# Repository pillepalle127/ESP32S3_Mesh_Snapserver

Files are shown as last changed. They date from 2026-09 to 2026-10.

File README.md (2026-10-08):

<picture>
  <source media="(prefers-color-scheme: dark)" srcset="docs/logo/snapmesh-logo-dark.svg">
  SnapMesh
</picture>

# ESP32-S3 Mesh Snapserver

**Stand:** 2026-09-29 · **English:** [README.en.md](README.en.md)

Mehrere Lautsprecher spielen synchron dieselbe Musik, ohne Router, PC oder Kabel dazwischen. Die ESP32-S3 bauen sich
ihr eigenes Funknetz (ESP-Mesh-Lite) und reichen das Signal von Gerät zu Gerät weiter.

Damit könnt ihr:

* eine Quelle einspeisen und überall hören,
* Lautstärke und Verzögerung für jeden Lautsprecher einzeln einstellen,
* Durchsagen vom Handy machen,
* einen Subwoofer über die eingebaute Weiche anschließen,
* vorhandene Snapcast-Clients (PC, Android, iOS) und Snapcast-Apps mitnutzen.

Im Kern stecken zwei Funktionen, die sich eigentlich widersprechen: **Musik** soll ohne Aussetzer laufen und bekommt
dafür einige Sekunden Puffer. **Durchsagen** sollen sofort zu hören sein (keine Latenz). Ich habe es
auf ~90 ms runtergeschafft.

Alle Geräte haben dieselbe Firmware. Eins ist der **Server**, alle anderen sind **Clients**.

---

## Installation

Firmware und App liegen fertig unter [Releases](https://github.com/pillepalle127/ESP32S3_Mesh_Snapserver/releases).
Geflasht wird aus dem Browser, eine Entwicklungsumgebung ist nicht nötig.

**Benötigt:** ein ESP32-S3-Board je Standort mit mindestens 4 MB Flash und **Octal-PSRAM** (z. B. N16R8, N8R8), ein
USB-Kabel mit Datenleitungen und Chrome oder Edge am PC. Für die App ein Android-Handy.

### 1. Firmware aufspielen

1. **[Flash-Seite](https://pillepalle127.github.io/ESP32S3_Mesh_Snapserver/)** öffnen, Board anschließen (bei zwei
   Buchsen die mit „USB“).
2. **Installieren**, „USB JTAG/serial debug unit“ wählen, **Verbinden**.
3. **Bei Updates „Erase device“ nicht anhaken**, sonst sind die Einstellungen weg.

Taucht das Board nicht auf: anderes Kabel, oder BOOT halten und kurz RST drücken. Ohne Chrome geht es mit
[esptool](https://github.com/espressif/esptool/releases) und den Einzeldateien aus dem Release:
```bash
esptool --chip esp32s3 --before usb_reset write_flash 0x0 bootloader.bin 0x8000 partition-table.bin 0x10000 snapmesh-app.bin 0x3d0000 ota_data_initial.bin
```

### 2. Einrichten

1. Mit dem offenen WLAN **`ESP32_provisioning_…`** verbinden und **http://192.168.5.1/** öffnen.
2. Rolle, Mesh-Name und Passwort eintragen (auf allen Geräten gleich), **Save**.

Erst den Server einrichten, dann die Clients. Mehr unter [Web-UI](#web-ui).

### 3. App (Android)

**`SnapAnnounce-….apk`** vom [Release](https://github.com/pillepalle127/ESP32S3_Mesh_Snapserver/releases) aufs Handy
laden und installieren. Handy ins Mesh-WLAN, App öffnen, fertig.

---

## Hardware

Zwei Aufbauten laufen bei mir:

* **Komplettsystem** im Verstärker: PCM5102A als Ausgang, TinySine AudioB I2S V2r0 als Bluetooth-Eingang, der über
  einen Pegelwandler TXB0104 am ESP hängt.
* **[SnapStreamer](#bauvorschlag-snapstreamer):** ein Bauvorschlag für einen reinen Empfänger mit PCM5102A.

Geeignet ist jeder ESP32-S3 mit mindestens 4 MB Flash, Octal-PSRAM und USB-Serial/JTAG, zum Beispiel ein
YD-ESP32-S3 N16R8
([Schaltplan V1.4](https://github.com/vcc-gnd/YD-ESP32-S3/blob/main/5-public-YD-ESP32-S3-Hardware%20info/YD-ESP32-S3-SCH-V1.4.pdf)).
Zwei 10-kΩ-Potis sind optional. Als Status-LED dient die WS2812, die auf vielen Boards schon sitzt. Die
Standardbelegung könnt ihr ändern (siehe [Pins](#pins)):

| GPIO | Funktion |
|---|---|
| 12 | BCLK (PCM5102A BCK, TinySine BCLK) |
| 14 | LRCLK (PCM5102A LCK, TinySine LRCLK) |
| 11 | DIN ← TinySine DOUT |
| 13 | DOUT → PCM5102A DIN |
| 10 | Lautstärke-Poti (Schleifer) |
| – | Delay-Poti (Vorgabe: keiner) |
| – | Ein/Aus-Taster gegen GND (Vorgabe: keiner) |
| 48 | WS2812-Status-LED |

---

## Bauvorschlag: SnapStreamer

Ihr habt einen Verstärker oder Aktivlautsprecher und wollt ihn ins Mesh holen? Der SnapStreamer ist meine Idee
dazu: ESP32-S3, DAC und Akku so dicht wie möglich in einem kleinen Gehäuse. Schrumpfschlauch oder ein vorhandenes
Gehäuse tun es natürlich auch.

<table>
  <tr>
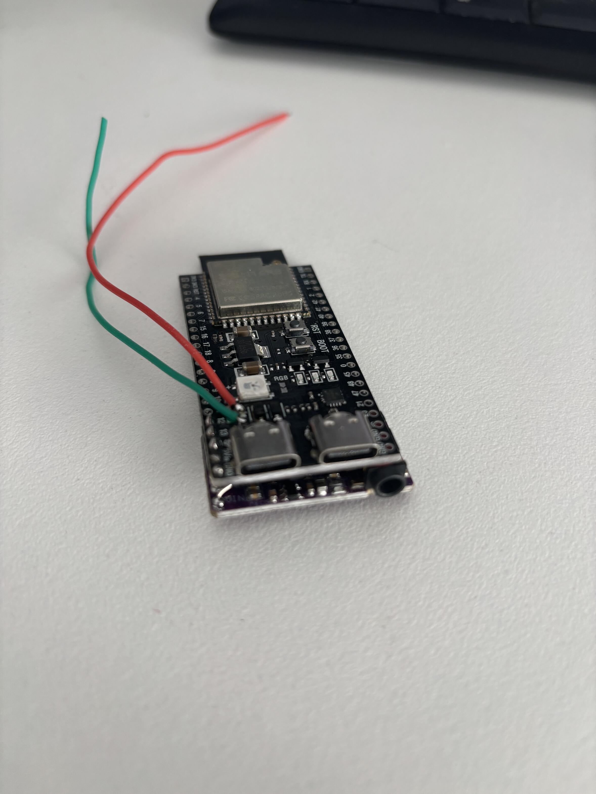
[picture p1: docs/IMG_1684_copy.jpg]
Platine von oben: ESP32-S3-Board mit dem PCM5102A darunter
    <td valign="top"></td>
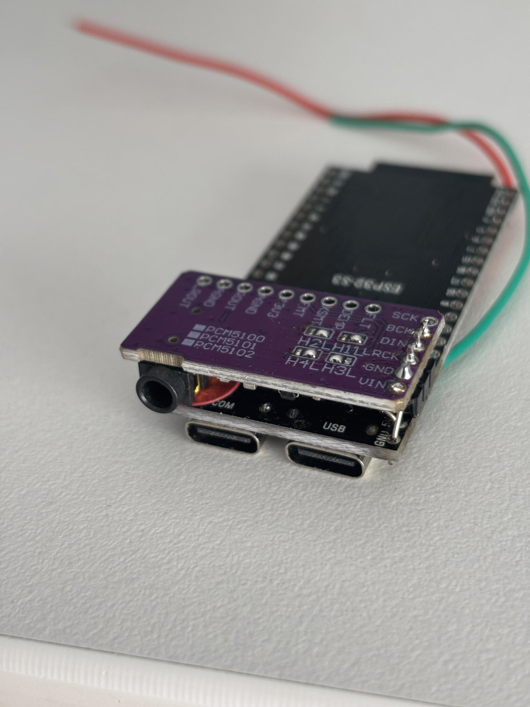
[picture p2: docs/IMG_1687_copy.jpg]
Von unten: PCM5102A-Modul unter dem ESP32-S3-Board
    <td valign="top"></td>
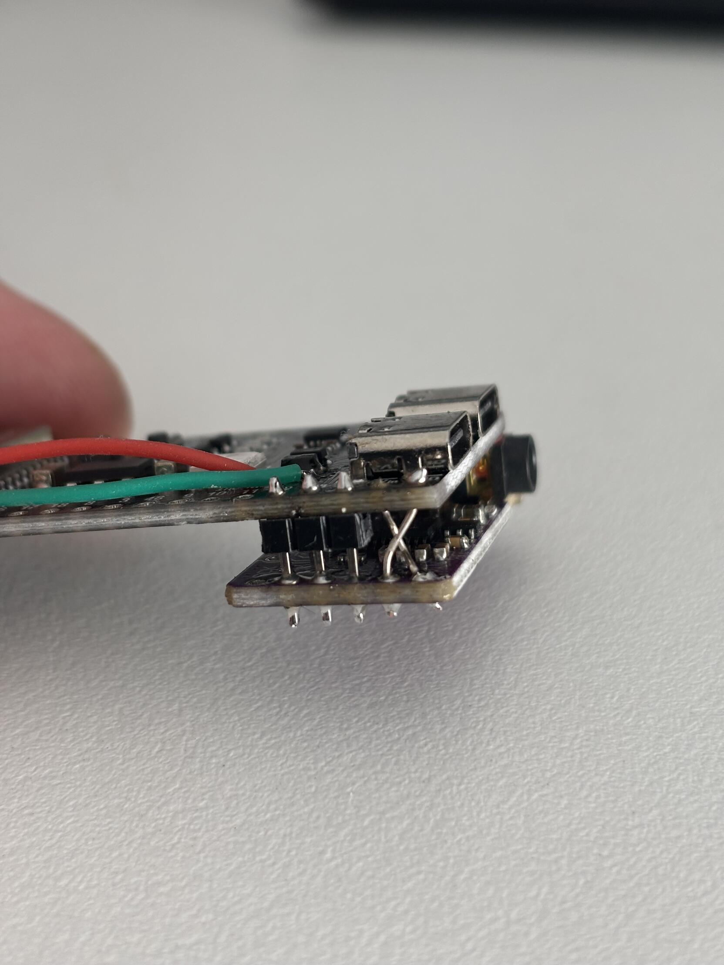
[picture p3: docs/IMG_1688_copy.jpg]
Von der Seite: GND und VIN gekreuzt
    <td valign="top"></td>
  </tr>
</table>

Der PCM5102A sitzt über kurze Stiftleisten direkt unter dem ESP32-S3-Board. Die LEDs bleiben sichtbar, RST und
BOOT erreichbar, Klinke und USB-Buchsen liegen auf einer Ebene an einer Stirnseite. GND und VIN müssen dabei
gekreuzt werden (in der Seitenansicht als X zu sehen).

Die rote und grüne Leitung (optional) führen die 5 V der ESP-Buchse zum TP4056: eine Buchse zum Programmieren und
Laden. Ladestrom auf 500 mA gesenkt (Verlustleistung). Der Akku hängt an VIN, nicht an 3V3: Die Zelle hat bis 4,2 V,
der ESP verträgt max. 3,6 V. Die Alternative wäre ein Buck-Boost-Wandler. Ein Poti mit Schalter schaltet ein und
regelt die Lautstärke.

> [!WARNING]
> Li-Ionen-Akkus können brennen, wenn sie kurzgeschlossen, beschädigt oder falsch geladen werden. Nehmt nur Zellen
> und Lademodule mit Schutzschaltung, isoliert offene Kontakte, quetscht die Zelle nicht ins Gehäuse und ladet nicht
> unbeaufsichtigt.

### Stückliste

| Teil | Typ / Hinweis | Anzahl |
|---|---|---|
| ESP32-S3-Board | ≥ 4 MB Flash, Octal-PSRAM, z. B. YD-ESP32-S3 N16R8 | 1 |
| WLAN-Antenne | optional, 2,4 GHz mit U.FL-Kabel; nur für Boards mit U.FL-Anschluss, verbessert mit guter Antenne den Empfang | 1 |
| DAC-Modul | PCM5102A mit 3,5-mm-Klinkenbuchse | 1 |
| Lademodul | TP4056 mit Schutzschaltung (DW01) | 1 |
| Akku | 18650 Li-Ion mit Zellkontakten | 1 |
| Poti mit Schalter | 10 kΩ linear (B10K), Schalter für die Versorgung, mit Drehknopf | 1 |
| Gehäuse | 3D-Druck: Unterteil (PETG), Deckel (PETG transparent) | 1 |

### Gehäuse

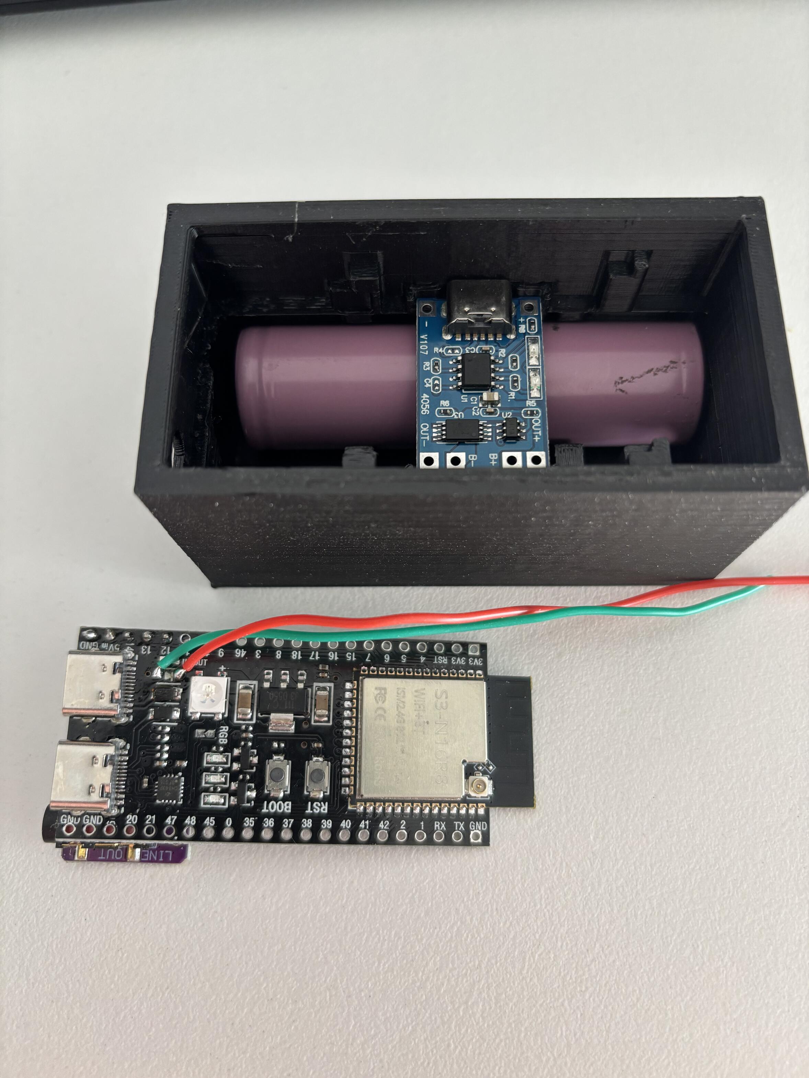
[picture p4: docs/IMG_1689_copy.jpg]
Gehäuseunterteil mit 18650-Zelle und TP4056, daneben die Platine


<table>
  <tr>
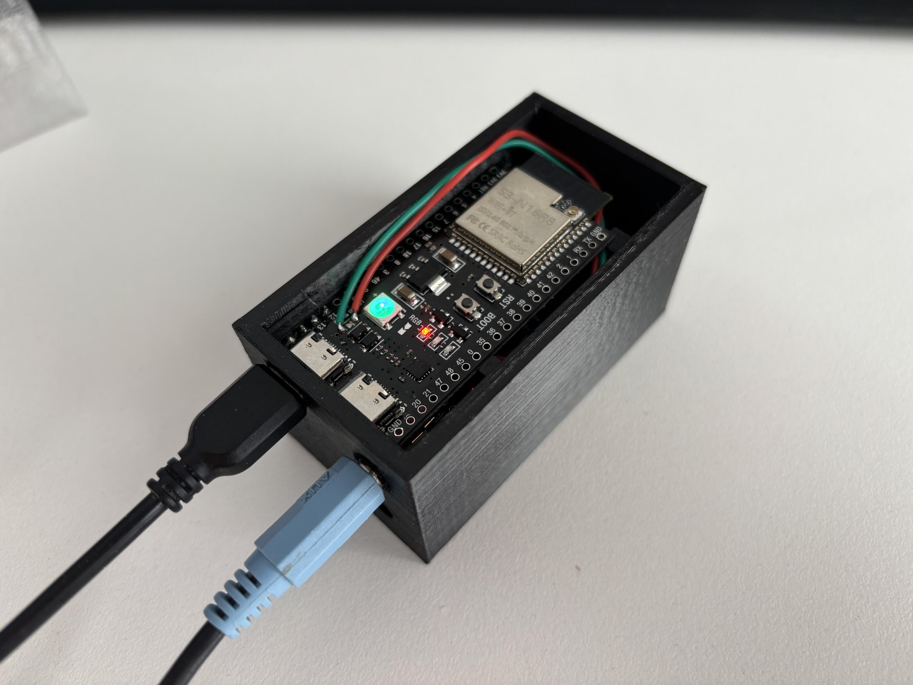
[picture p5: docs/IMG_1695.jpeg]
Offenes Gehäuse mit Platine, USB und Klinke angesteckt
    <td valign="top"></td>
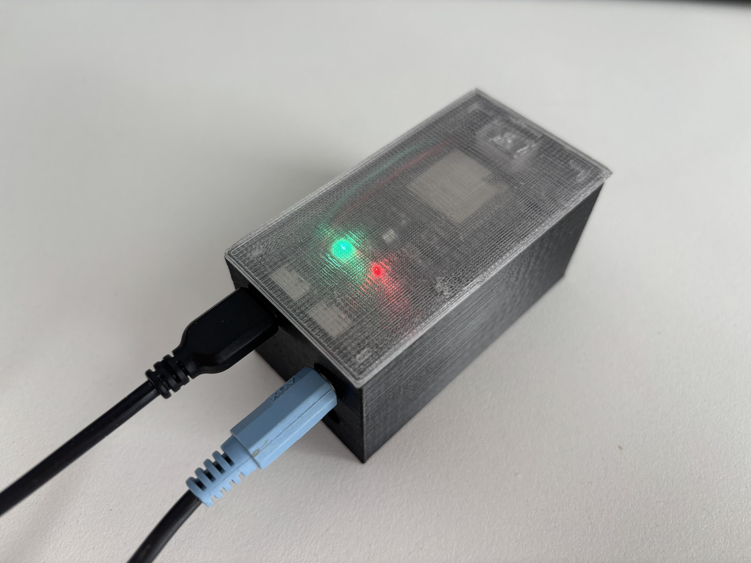
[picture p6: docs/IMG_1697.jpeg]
Geschlossenes Gehäuse, die Status-LED leuchtet durch den Deckel
    <td valign="top"></td>
  </tr>
</table>

Unten im Gehäuse liegen Akku und Lademodul, darüber die Platine. USB-C und Klinke sind von der Stirnseite zugänglich,
die Steckkräfte werden ins Gehäuse geführt. Die Status-LED scheint durch den Deckel. Die Konstruktionsdaten
liegen in [`mechanics/housing/`](mechanics/housing/): das FreeCAD-Modell `Snapstreamer2.FCStd` sowie Unterteil
(`Snapstreamer2-SStreamer GuT.3mf`) und Deckel (`Snapstreamer2-SStreamer GoT.3mf`) druckfertig als 3MF.

---

## Signalweg

```text
I2S in (Stereo) ─► L+R → Mono ─┬─► Opus ─► Snapcast TCP 1704 ─► Clients
                               │
                               └─► Delay-Line ─► DSP ─► I2S out
```

Der Server verzögert seinen eigenen Lautsprecher um die Pufferzeit, damit er mit den Clients zusammen spielt. Die
Clients spielen aus ihrem Puffer in dieselbe Kette.

| Stufe, in Reihenfolge | Weiche aus | Weiche an | Durchsage |
|---|---|---|---|
| Puffer, Delay, Delay-Poti | X | X | - |
| Mono (L+R)/2 | X | X | - |
| Subsonic-Hochpass | - | X | X |
| Gain Sub / Breitband | - | X | X |
| Sub-Phase 180° | - | X | X |
| Kompressor | X | X | - |
| Poti, Lautstärke | X | X | X |
| Begrenzer −0,5 dBFS, 1,3 ms Vorausschau | X | X | X |

**X** verfügbar, **-** nicht verfügbar.

Nur Puffer, Delay und die Vorausschau des Begrenzers (1,3 ms) verzögern. Durchsagen umgehen alles, was
verzögert.

---

## Synchronisation

Die Clients gleichen ihre Uhr laufend mit dem Server ab und spielen jeden Block zu seiner Soll-Zeit. Die Uhr ergibt
sich aus einer Ausgleichsgeraden durch die schnellsten Messungen der letzten 64 s. Kleine Abweichungen gleicht ein
Resampler aus. Korrigiert der Server seine Zeitachse, springen alle Clients beim selben Block. Bei mir liegen die
Lautsprecher damit unter 2–3 ms beieinander.

---

## Netzwerk

Die Geräte nutzen die Ports 80, 1704, 1705 und 1706 (UDP). Die Clients bauen alle Verbindungen selbst auf, so
erreichen sie den Server aus jeder Mesh-Ebene. Per mDNS heißen die Geräte `snapserver-<MAC>.local` bzw.
`snapclient-<MAC>.local`.

Ohne Konfiguration, nach einem Factory Reset oder wenn das Mesh wiederholt nicht zustande kommt, öffnet das Gerät das
WLAN `ESP32_provisioning_<MAC>` zum Einrichten. Nach 3 Minuten ohne Speichern schaltet es den Funk ab.

---

## Web-UI

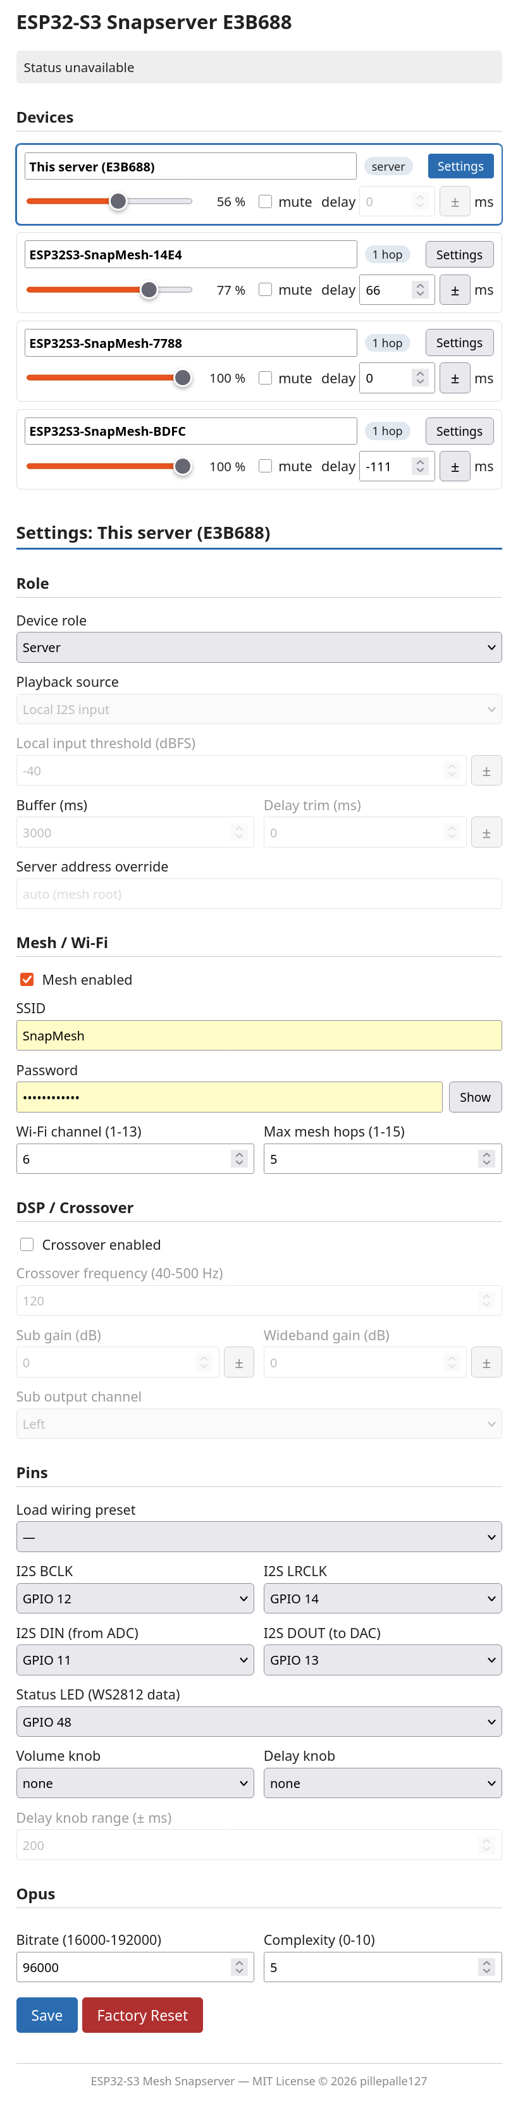
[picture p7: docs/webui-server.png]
Einstellungsseite des Servers mit Geräteliste


Jedes Gerät hat eine Einstellungsseite unter seiner IP-Adresse oder seinem mDNS-Namen. Die Werte bleiben bei
Updates erhalten, **Werkseinstellungen** setzt alles zurück.

### Geräteliste (Server)

Name, Lautstärke, Stumm und Delay jedes Lautsprechers, auch aus Snapcast-Control-Apps. Der Server merkt sich die
Werte je Gerät. **Einstellungen** lädt die Einstellungen eines Clients, egal wie tief er im Mesh hängt.

### Einstellungen

* **Rolle:** Server oder Client.
* **Puffer (Server):** Vorsprung gegen Funkaussetzer, Vorgabe 3000 ms, gilt für alle Geräte.
* **Wiedergabe (Client):** Quelle, Lautstärke und Stumm. Solange ein Server verbunden ist, stellt er die Lautstärke ein.
* **Mesh / WLAN:** Name, Passwort und Kanal, auf allen Geräten gleich.
* **Weiche:** Trennfrequenz, Gain für Sub und Breitband (−24 bis +18 dB), Sub-Phase 180°.
* **Subsonic:** Hochpass im Sub-Zweig gegen Tiefbass unterhalb der Abstimmung, Richtwert 0,75 × F3.
* **Kompressor:** Schwelle, Verhältnis, Aufholen.
* **Pins:** siehe [Pins](#pins).
* **Opus (Server):** Bitrate und Rechenaufwand des Encoders, eingeklappt.

Weiche, Kompressor und Lautstärke werden beim Ändern übernommen, alles andere mit **Speichern**. Rolle, Mesh, Puffer und Pins
starten das Gerät neu. Die Pins sind eingeklappt.

### Kompressor einstellen

1. Sub und Breitband mit den Gains abgleichen, den lauteren Zweig auf 0 dB. Poti und Quelle auf Maximum.
2. Kompressor an, Verhältnis 3, Aufholen 0 dB.
3. Schwelle ab −30 dBFS senken, bis laute Stellen um 3–6 dB abgesenkt werden.
4. Aufholen erhöhen, bis der Begrenzer nur noch selten eingreift, höchstens um 3 dB.
5. Poti durchdrehen: Das letzte Stück muss noch lauter werden, sonst ist das Aufholen zu hoch.

Klingt es platt oder pumpt es, die Schwelle höher oder das Verhältnis kleiner stellen. Mit 1:1 ist der Kompressor
eine reine Verstärkung. Kompressor und Begrenzer melden ihre Absenkung alle 5 s im seriellen Log.

---

## Pins

Die Pins lassen sich in der Web-UI umbelegen, ohne neu zu flashen. Die Firmware lehnt Doppelbelegungen und
ungeeignete Pins ab. Startet das Gerät mit einer neuen Belegung nicht, fällt es auf die Standardbelegung zurück.

### I2S-Takt

Normal erzeugt der ESP BCLK und LRCLK. Gibt ein anderes Gerät den Takt vor, zum Beispiel ein DSP wie der ADAU1701,
stellt ihr **I2S-Takt** auf **Extern**. Dann laufen Quelle, DAC und ESP auf dessen Takt. Ohne diesen Takt bleibt es
still.

### Ein/Aus-Taster

Ein Taster von einem GPIO (1–21) gegen GND, ohne weitere Bauteile. 2 s halten schaltet aus, 1 s halten schaltet ein.
Aus heißt Deep Sleep: Nur der ESP schläft, DAC, Verstärker und Spannungsregler am Akku ziehen weiter Strom.

### Potis

Zwei optionale 10-kΩ-Potis regeln Lautstärke und Delay direkt am Gerät. Der Schleifer gehört an einen ADC1-Pin
(GPIO 1–10). Die Drehrichtung lässt sich umkehren.

### Status-LED

Eine WS2812 blitzt beim Start rot, grün und blau und zeigt danach den Zustand:

| Anzeige | Bedeutung |
|---|---|
| blau, blinkt langsam | Einrichtung |
| rot, blinkt schnell | kein Netz |
| orange, blinkt | kein Server |
| Pegel grün bis rot | Wiedergabe |
| Pegel, pulsiert | Durchsage |

<br clear="all">

---

## SnapAnnounce App

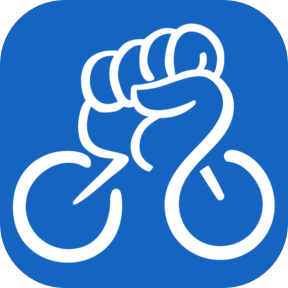
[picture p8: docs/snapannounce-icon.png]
SnapAnnounce-Icon


Mit **SnapAnnounce** startet ihr Durchsagen direkt im Mesh. Ohne extra Hardware und ohne Kabel, alles übers Handy.
Leider nur für Android, ich habe keinen Mac und kaufe mir auch keinen.

Die Musik pausiert solange. Weil Durchsagen ohne Puffer laufen, sind sie empfindlicher gegen Funkaussetzer und
reichen deshalb **nur zwei Mesh-Ebenen** tief.

<table>
  <tr>
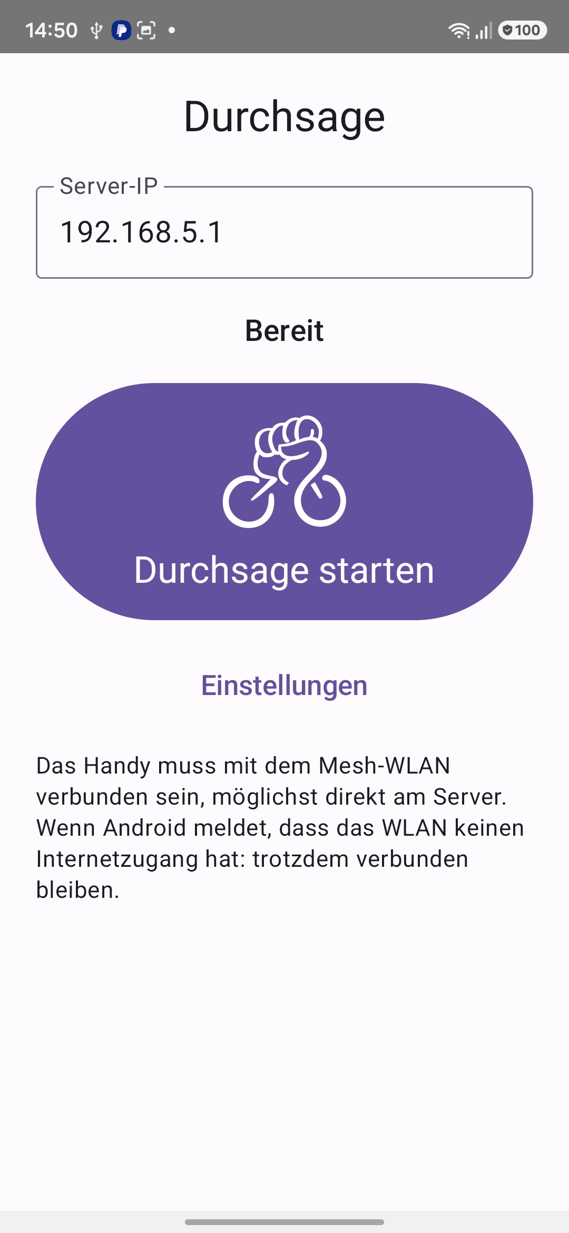
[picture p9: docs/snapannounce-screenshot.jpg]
SnapAnnounce, Durchsage
    <td valign="top"></td>
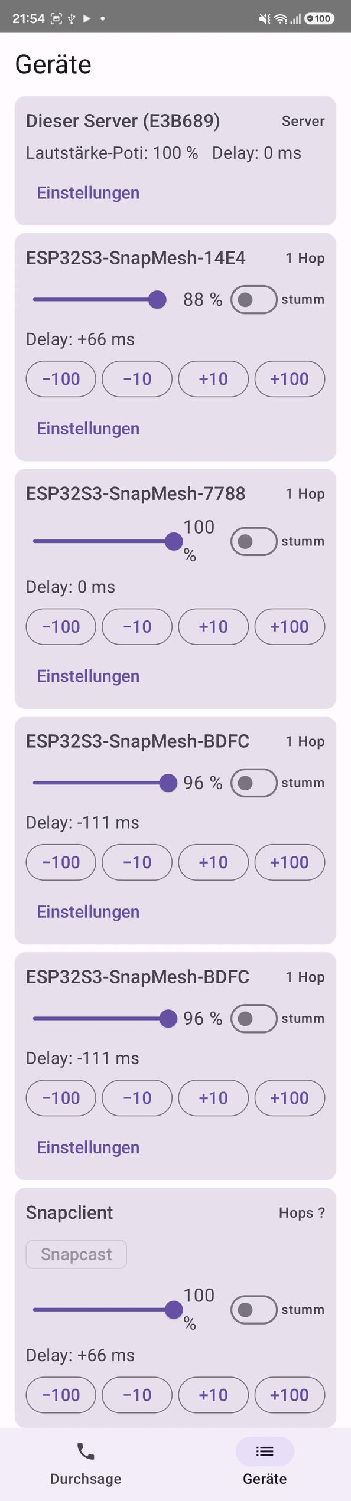
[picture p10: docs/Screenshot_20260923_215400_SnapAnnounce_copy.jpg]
SnapAnnounce, Geräte
    <td valign="top"></td>
  </tr>
</table>

---

## Lizenz

MIT, siehe [LICENSE](LICENSE). Die Lizenzen der Fremdkomponenten liegen jedem Release als
`THIRD_PARTY_LICENSES.txt` bei.

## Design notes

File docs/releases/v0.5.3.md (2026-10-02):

Bugfix-Release für die Clients.

## Behoben

* **Latenz und Verzögerung wirkten erst nach Minuten.** Eine Änderung unter 100 ms hat der Client langsam
  herangeregelt, für 55 ms brauchte er Minuten. Jetzt springt er sofort auf den neuen Wert, auf das Sample genau. So
  lässt sich jeder Lautsprecher nach Gehör einstellen.
* **Ein Client blieb lange daneben.** Nach einem Neuverbinden lag bei mir ein Client viele Minuten 18 ms hinter den
  anderen. Liegt ein Client jetzt eine halbe Sekunde lang mehr als 5 ms daneben, springt er sofort zurück.

## Update von v0.5.2

* Beide Korrekturen stecken in den Clients, der Server ändert sich nicht. Aktualisiert die Clients.
* Mit den vier Einzeldateien bleiben die Einstellungen erhalten (Browser ohne „Erase device“ oder esptool, siehe
  unten).

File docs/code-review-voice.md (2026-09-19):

# Code-Review: Sprachdurchsagen (Branch `test/voice`)

Stand 2026-09-19, Basis `7ba6726` + uncommittete Änderungen.

**Geprüft:** alle Änderungen für die Sprachdurchsagen — `main/voice_announce.c/.h`,
die Anpassungen in `audio_sink.c`, `audio_i2s.c`, `snapserver.c`, `snapcontrol.c`,
`status_led.c`, `app_main.c`, dazu die Android-App (`android/SnapAnnounce/`) und
`tools/voice_test.py`.

**Nicht geprüft:** der bereits committete Teil des Branches gegenüber `main`.
Nichts davon lief auf Hardware. Die App wurde nicht gebaut, weil auf dem
Rechner kein Android-SDK installiert ist. Alle Befunde unten sind am Code
nachvollzogen; die Szenarien sind hergeleitet, nicht beobachtet.

## Übersicht

| Nr | Schwere | Ort | Befund |
|----|---|-----|---|
| K1 | kritisch | `voice_announce.c:152` | Level-2-Clients werden nicht stummgeschaltet |
| K2 | kritisch | `voice_announce.c:451` | Clients verwerfen jede weitere Durchsage |
| K3 | kritisch | `voice_announce.c:147` | 3,4 KB Array auf dem 6-KB-Stack von `ctrl_conn_task` |
| K4 | kritisch | `audio_sink.c` (Player/Ring) | Bei Durchsagen über ca. 4 s kommt die Musik auf Level-1 nicht nahtlos zurück |
| H1 | hoch | `voice_announce.c` / `snapserver.c:1675` | Clients, die während einer Durchsage (neu) verbinden, sind nicht stumm |
| H2 | hoch | `voice_announce.c:176/227` | Start/Stop-Races: Clients bleiben dauerhaft stumm oder der Zustand hängt |
| H3 | hoch | Architektur | Level-1-Clients spielen Musik, bis das erste Sprachpaket ankommt |
| M1 | mittel | `voice_announce.c:305` | Race beim Nachstellen des Watchdogs kann eine schnelle Folgedurchsage abwürgen |
| M2 | mittel | `voice_announce.c:213` | Stop-Arbeit läuft im esp_timer-Task: blockiert, Stack nicht geprüft |
| M3 | mittel | `audio_sink.c:869`, `audio_i2s.c:667` | Mailbox ohne Vorpuffer; bei Überlauf fliegen die neuesten Samples raus |
| M4 | mittel | `voice_announce.c` | Lautstärke-/Mute-Änderungen während einer Durchsage gehen verloren |
| M5 | mittel | `VoiceAnnounceService.kt:166` | App-Timeout von 1,5 s gegen synchrones Muten auf dem Server |
| N1 | niedrig | `audio_sink.c:753` | LED bleibt im Durchsage-Puls hängen |
| N2 | niedrig | `voice_announce.c` | UDP 1706 nimmt während einer Durchsage Audio von jedem Absender an |
| N3 | niedrig | `snapcontrol.c:471`, `VoiceAnnounceService.kt:178` | Ablehnung wird als „Method not found“ gemeldet |

K1 bis K3 lassen sich mit wenigen Zeilen beheben. K4 und die H-Punkte brauchen
die beiden Umbauten im Abschnitt „Empfohlene Umbauten“.

**Stand 2026-09-19 abends:** Alles außer M3 ist umgesetzt. Die Firmware und
die App bauen, auf Hardware getestet ist davon noch nichts. K3 war vorher auf
Hardware reproduziert (Stack-Overflow in `snapctrl_conn` beim ersten
`Voice.Start`).

| Punkt | Umsetzung |
|---|---|
| K1, H1, M4 | Umbau A: `snapserver_set_announcement()`; `send_server_settings()` mutet per MAC-Test zusätzlich zum App-Mute, auch beim Handshake. Einmal pro Sekunde wird nachgeprüft (Ebenenwechsel). |
| K2 | Client setzt die Sequenz nach 400 ms Pause zurück; außerdem nummeriert der Server seinen Strom jetzt selbst durchgehend. |
| K3 | Client-Snapshot im PSRAM; das Stummschalten läuft ohnehin nicht mehr im RPC-Handler. |
| K4 | Umbau B: Die Durchsage ist ein Overlay, die Musik wird darunter weiter berechnet und nur nicht ausgegeben. |
| H2 | Ein Mutex über Start/Stop; es gibt keinen gespeicherten Mute-Zustand mehr, der überschrieben werden könnte. |
| H3 | Stille-Pakete an Level 1 ab `Voice.Start`, bis das Handy liefert. |
| M1, M2 | Umbau C: keine esp_timer mehr, Watchdogs per Zeitstempel im `voice_server_task`. |
| M5 | Der RPC mutet nicht mehr synchron; die App wartet 5 s auf Antworten. |
| N1 | Die LED wird während der Durchsage jeden Frame gesetzt und danach passend zur Quelle zurückgestellt. |
| N2 | Nur UDP von der IP der Owner-Verbindung wird verteilt. |
| N3 | Ablehnung als `result.busy`; die App unterscheidet „läuft schon“ und „Firmware kann das nicht“. |
| M3 | offen, nach dem ersten Hörtest |

Nebenbei gefunden und behoben: `tools/voice_test.py` hätte bei einer
Ablehnung `Voice.Stop` geschickt und damit die fremde Durchsage beendet.

---

## Kritisch

### K1 — Level-2-Clients werden nicht stummgeschaltet
**Ort:** `mute_non_level1_clients()`, `voice_announce.c:152`

Ob ein Client auf Level 1 hängt, wird hier über die **IP** entschieden. Wegen
NAPT kommt ein Level-2-Client beim Server aber mit der IP seines
Level-1-Parents an (dieselbe Ursache wie `rssi=127` im Stats-Log). Seine IP
steht damit in der Level-1-Liste, er wird übersprungen und spielt während der
Durchsage weiter Musik. Genau das darf laut Anforderung „keinesfalls“ passieren.

Die Verteilerliste selbst ist korrekt, denn sie entsteht über den MAC-Abgleich
in `snapserver_get_level1_client_ips()`. Falsch ist nur die Mute-Prüfung.

**Fix:** Auch hier über die MAC entscheiden (`level1_match_rssi()` in
`snapserver.c`). Am saubersten löst das der Umbau A unten.

### K2 — Clients verwerfen jede weitere Durchsage
**Ort:** `voice_client_task()`, `voice_announce.c:451`

`last_sequence` und `have_sequence` werden nie zurückgesetzt. App und
`voice_test.py` beginnen aber jede Durchsage bei Sequenz 0. Nach einer
30-s-Durchsage (3000 Pakete) gelten bei der nächsten die ersten ~30 s als
veraltet und werden verworfen. Weil die übrigen Clients gleichzeitig stumm
sind, ist dann nirgends etwas zu hören. Das zeigt sich schon beim zweiten
Lauf von `voice_test.py` in Stufe 2.

**Fix:** Den Sequenz-Zustand zurücksetzen, wenn seit dem letzten Paket mehr
als `VOICE_INACTIVITY_TIMEOUT_US` (400 ms) vergangen sind. Zusätzlich einen
großen Rückwärtssprung (z. B. mehr als 1000 Pakete) als neue Sitzung werten.

### K3 — 3,4 KB Array auf dem 6-KB-Stack von `ctrl_conn_task`
**Ort:** `mute_non_level1_clients()`, `voice_announce.c:147`

`snapserver_client_info_t clients[SNAPSERVER_MAX_CLIENTS]` braucht 10 × 344 B,
also etwa 3,4 KB Stack. Aufgerufen wird die Funktion tief in
`process_line → handle_request_object → build_result →
voice_announce_rpc_start`, darunter folgen noch
`snapserver_set_client_volume → send_server_settings → send_all` samt
`ESP_LOGI`. `CTRL_CONN_STACK` ist 6144 B.

`snapcontrol.c:62-69` beschreibt, dass genau dieses Array aus genau diesem
Grund schon einmal vom Stack ins PSRAM verlegt wurde. Dazu kommt die Lehre
aus dem `snapsend3`-Überlauf: Der Pfad läuft erst bei der ersten Durchsage
mit mehreren Clients überhaupt an.

**Fix:** Das Array per `heap_caps_malloc(…, MALLOC_CAP_SPIRAM)` holen oder
statisch anlegen. Statisch geht, sobald Start und Stop wie in H2 serialisiert
sind.

### K4 — Bei Durchsagen über ca. 4 s kommt die Musik auf Level-1 nicht nahtlos zurück
**Ort:** Zusammenspiel von `player_task` (VOICE-Zweig) und
`audio_sink_feed_network()` in `audio_sink.c`

Die Architekturentscheidung setzt darauf, dass der Ring während der Durchsage
weiterläuft und danach sofort aktuelles Audio bereitsteht. Das stimmt nur für
kurze Durchsagen:

1. Im Normalbetrieb hält der Ring etwa `buffer_ms` (3 s); seine Kapazität ist
   `2 × buffer_ms` (6 s). Solange VOICE aktiv ist, liest der Player nichts.
   Nach ~3 s ist der Ring voll, und `ring_write()` schneidet neue Chunks ab.
2. `fill` bleibt dabei konstant, während die Chunk-Zeitstempel weiterlaufen.
   Nach einer weiteren Sekunde gilt `gap_us > STREAM_RESTART_US`: Der Ring
   wird geleert und `s_network_ready = false` gesetzt (`audio_sink.c:924-931`).
3. Das wiederholt sich zyklisch. Wie es beim Ende der Durchsage aussieht,
   hängt vom Zeitpunkt ab:
   - Ist der Ring unter 80 % von `buffer_ms` gefüllt, folgt bis zu **2,4 s
     Stille** durch den Prebuffer.
   - Sonst stehen bis zu 6 s Rückstand im Ring, und der Scheduler springt per
     Hard-Resync nach vorn.

Level-2-Clients betrifft das nicht, weil sie gemutet weiterlaufen. Level-1-
und Level-2-Lautsprecher setzen danach also auch unterschiedlich wieder ein.
Übliche Durchsagen (5–30 s) liegen alle in diesem Bereich.

**Fix:** Siehe Umbau B.

---

## Hoch

### H1 — Clients, die während einer Durchsage (neu) verbinden, sind nicht stumm
**Ort:** Die Mute-Liste entsteht nur einmal in `voice_announce_rpc_start()`;
`snapserver.c:1675` setzt `muted = false` für jeden neuen Slot.

Im dynamischen Mesh ist ein Reconnect während einer 30-s-Durchsage
realistisch. Ein Level-2-Client, der sich neu verbindet, bekommt
`muted=false` und spielt Musik. Ebenso ein Client, der mitten in der
Durchsage von Level 1 auf Level 2 rutscht: Er fällt aus der Verteilerliste
(der Re-Poll erkennt das), wird aber nie gemutet.

**Fix:** Umbau A. Der Server entscheidet dann bei **jeder**
`ServerSettings`-Nachricht, auch beim Handshake.

### H2 — Start/Stop-Races
**Ort:** `voice_stop_internal()` (`:176`) und `voice_announce_rpc_start()`
(`:227`)

Beide Funktionen setzen bzw. löschen `s_owner_fd` zuerst und arbeiten danach
ohne Schutz auf `s_muted_clients`/`s_muted_count`. Das Wiederherstellen
blockiert pro Client bis zu `SEND_MUTEX_WAIT_MS` (1 s).

- **Stop, dann sofort Start:** Der neue Start liest die noch gemuteten
  Clients als `muted=true`, speichert das als „Originalzustand“ und
  überschreibt die Liste, die gerade wiederhergestellt wird. Diese Clients
  bleiben nach der nächsten Durchsage **dauerhaft stumm**.
- **Stop (von einer anderen Verbindung) während eines Starts:** Das Restore
  läuft über eine halb gefüllte Liste, danach mutet der Start den Rest und
  setzt `audio_i2s_set_voice_active(true)` sowie die LED. `s_owner_fd` ist
  dann aber `-1`. Ergebnis: Der Server-Lautsprecher bleibt stumm, weil der
  Voice-Override aktiv ist, aber keine Pakete mehr angenommen werden. Clients
  bleiben gemutet, die LED pulsiert — bis zum nächsten Start/Stop.

**Fix:** Ein FreeRTOS-Mutex (kein Spinlock, es wird blockiert gesendet), der
Start und Stop jeweils komplett umschließt. Mit Umbau A entfällt ohnehin der
gespeicherte Zustand, der hier überschrieben wird.

### H3 — Level-1-Clients spielen Musik, bis das erste Sprachpaket ankommt
**Ort:** Architektur; Level-1 wird nur über ankommende Pakete umgeschaltet.

Der Plan nahm für dieses Fenster „typischerweise << 100 ms“ an. Das ist zu
optimistisch: Die App meldet sich zuerst beim Server an und öffnet erst
danach das Mikrofon, und `VOICE_COMMUNICATION` braucht auf manchen Geräten
mehrere hundert ms. Deshalb gibt es `VOICE_START_GRACE_MS = 3000`. So lange
laufen Level-1-Lautsprecher mit Musik weiter, während Level-2 schon stumm ist.

**Fix:** Der Server schickt ab `Voice.Start` sofort Stille-Pakete an die
Level-1-Clients, bis echtes Audio vom Handy kommt. Die Clients wechseln dann
sofort auf VOICE. Das passt zu Umbau C.

---

## Mittel

### M1 — Race beim Nachstellen des Watchdogs
**Ort:** `voice_server_task()`, `voice_announce.c:305`

Der Task prüft unter Lock, ob eine Durchsage aktiv ist, und stellt den Timer
danach ungeschützt neu (`esp_timer_stop` + `start_once`). Fällt ein Stop
genau dazwischen, bleibt der Timer mit 1 s gestellt. Ein schneller neuer
Start ruft `esp_timer_start_once` auf einen laufenden Timer auf; der Fehler
wird ignoriert, die 3-s-Anlauffrist greift nicht, und die Durchsage wird
nach ~1 s beendet, bevor das Handy-Mikrofon läuft.

Nebenbei: 100 Timer-Stops/-Starts pro Sekunde sind unnötige Last.

**Fix:** Umbau C. Nur noch Zeitstempel (`s_last_packet_us`, `s_started_us`)
schreiben und periodisch prüfen, statt pro Paket den Timer neu zu stellen.

### M2 — Stop-Arbeit im esp_timer-Task
**Ort:** `silence_watchdog_cb()`/`max_duration_cb()`, `voice_announce.c:213`

Das ist bereits im Code kommentiert, aber nicht behoben. Das Restore
blockiert den gemeinsamen esp_timer-Task bis zu 1 s pro Client. Außerdem ist
nicht geprüft, ob `CONFIG_ESP_TIMER_TASK_STACK_SIZE=3584` für
`send_server_settings → client_send_msg → send_all` plus zwei `ESP_LOG*`
reicht. Es ist wieder ein Pfad, der erst im Fehlerfall läuft.

**Fix:** Umbau C. Der Stop läuft dann im `voice_server_task` (PSRAM-Stack,
blockieren erlaubt).

### M3 — Mailbox ohne Vorpuffer, verwirft bei Überlauf die neuesten Samples
**Ort:** `audio_sink_feed_voice()` (`audio_sink.c:869`),
`audio_i2s_feed_voice()` (`audio_i2s.c:667`)

- **Kein Vorpuffer:** Pakete kommen alle 10 ms mit 480 Samples, der Player
  nimmt alle 20 ms 960. Kommt ein Paket etwas zu spät, wird die Hälfte des
  Frames mit Nullen gefüllt (10 ms Lücke, hörbares Knacken). Die Verspätung
  bleibt danach als +10 ms Latenz stehen, bis die 40 ms voll sind. Bei
  WLAN-Jitter im Mesh wird das regelmäßig passieren.
- **Überlauf verwirft Neues:** Ist die Mailbox voll, werden die **neuen**
  Samples verworfen. Das widerspricht „das Frischeste spielen“: Die Latenz
  klebt bei 40 ms, und jeder WLAN-Burst reißt Lücken ins neueste Audio.
  Taktdrift zwischen Handy und ESP (±50 ppm) führt zusätzlich zu einem
  Verlust bzw. Leerlauf etwa alle 200 s.

**Fix:** Erst ausgeben, wenn ~20 ms im Puffer liegen. Bei Überlauf das
Älteste verwerfen. Ob die Kapazität reicht (evtl. 60 ms), entscheidet der
Hörtest in Stufe 3.

### M4 — Lautstärke-/Mute-Änderungen während einer Durchsage gehen verloren
**Ort:** `mute_non_level1_clients()` / `restore_muted_clients()`

Die Durchsage überschreibt das `muted`-Feld, das auch die Steuer-App sieht.
Snapdroid und Co. zeigen die Lautsprecher währenddessen als stumm an, und
eine Lautstärkeänderung während der Durchsage wird beim Restore mit dem
alten Stand überschrieben.

**Fix:** Umbau A.

### M5 — App-Timeout von 1,5 s gegen synchrones Muten auf dem Server
**Ort:** `VoiceAnnounceService.kt:166` (`CONNECT_TIMEOUT_MS` gilt auch als
`soTimeout`)

`Voice.Start` antwortet erst, nachdem alle Nicht-Level-1-Clients ihre
`ServerSettings` bekommen haben. Das dauert bis zu 1 s pro Client, wenn
einer hängt. Die App meldet dann „Server antwortet nicht“ und schließt die
Verbindung. Der Server beendet die gerade gestartete Durchsage daraufhin über
den Disconnect-Hook wieder. Das Ergebnis ist konsistent, aber die Durchsage
schlägt ohne echten Grund fehl.

**Fix:** In der App ein längeres Lese-Timeout für `Voice.Start` (z. B. 5 s),
der Connect-Timeout bleibt kurz. Mit Umbau A muss der Server gar nicht mehr
synchron in `Voice.Start` muten.

---

## Niedrig

### N1 — LED bleibt im Durchsage-Puls hängen
**Ort:** `player_task`, `audio_sink.c:753`

Beim Wechsel VOICE → NONE (Netz während der Durchsage weg) setzt der Player
keinen LED-Zustand, bis `snapclient.c` irgendwann `NO_SERVER` oder `PLAYING`
setzt. Umgekehrt setzt ein Reconnect während der Durchsage `PLAYING`, und
der Puls verschwindet. Beides ist nur kosmetisch.

### N2 — UDP 1706 nimmt Audio von jedem Absender an
Während einer aktiven Durchsage verteilt der Server Pakete von **jedem**
Absender. Port 1705 hat ohnehin keine Authentifizierung (vorbestehend).

**Fix, billig:** Nur Pakete von der Peer-IP der Owner-Verbindung annehmen
(`getpeername(s_owner_fd)`). Die Prüfung stimmt auch hinter NAPT, weil TCP
und UDP dort dieselbe Quell-IP haben.

### N3 — Ablehnung wird als „Method not found“ gemeldet
**Ort:** `snapcontrol.c:471`, `VoiceAnnounceService.kt:178`

„Es läuft bereits eine Durchsage“ kommt als `-32601 Method not found` zurück.
Das ist für andere Controller irreführend. Die App wertet außerdem **jeden**
Fehler als „bereits aktiv“, auch den echten `-32601` einer Firmware ohne
Voice-Unterstützung.

**Fix:** Eigener Code (z. B. `-32000`, „announcement already active“), und
die App unterscheidet die beiden Fälle.

---

## Empfohlene Umbauten

### A — Durchsage-Mute als Serverzustand statt Überschreiben des Client-Mutes
*Löst K1, H1, M4, M5 und den gespeicherten Zustand hinter H2.*

- In `snapserver.c` ein Flag `s_announcement_active`.
- `send_server_settings()` sendet
  `muted = client->muted || (s_announcement_active && !is_level1(client->mac))`.
  `is_level1()` ist `level1_match_rssi()`, also derselbe MAC-Test wie für
  die Verteilerliste.
- `snapserver_set_announcement(bool)` setzt das Flag und schickt allen
  Clients neue `ServerSettings`. Beim Stop wird einfach neu gesendet; es gibt
  nichts zu speichern und nichts wiederherzustellen.
- Der Handshake neuer Clients nutzt automatisch dieselbe Regel (H1). Der
  Re-Poll im `voice_server_task` ruft zusätzlich einmal pro Sekunde
  `snapserver_set_announcement(true)` auf, damit Clients, die die Ebene
  wechseln, erfasst werden. Das sollte nur senden, wenn sich der effektive
  Mute-Zustand eines Clients geändert hat.
- `client->muted` bleibt der Wert aus der Steuer-App (M4).

### B — VOICE als Overlay über der weiterlaufenden Musik-Timeline
*Löst K4.*

Solange VOICE aktiv ist und die Basisquelle NETWORK wäre, ruft der Player
weiter `render_network_frame()` in einen Wegwerf-Puffer auf und gibt nur
stattdessen die Stimme aus. Die Musik läuft also still weiter, genau wie auf
den gemuteten Level-2-Clients. Dadurch bleiben Ring-Füllstand, Timeline und
Regelung unverändert; nach der Durchsage geht es ohne Prebuffer und synchron
mit Level 2 weiter.

Dazu `decide_source()` in „Basisquelle“ und „Voice-Override“ aufteilen. Der
Sonderfall „kein Flush beim Wechsel zu VOICE“ bleibt dabei harmlos.

### C — `voice_server_task` mit Empfangs-Timeout als einziger Zustandsbesitzer
*Löst H3, M1, M2 und nimmt den Timern die Arbeit ab.*

- `recvfrom()` mit `SO_RCVTIMEO` von ~10 ms.
- Bei jedem Durchlauf, mit Paket oder Timeout:
  - Watchdogs über Zeitstempel prüfen (Anlauffrist, 1 s Stille, 3 min Maximum).
  - Solange aktiv und noch nichts vom Handy kam, Stille-Pakete an Level 1
    schicken (H3).
  - Einen angeforderten Stop hier ausführen. RPC und Disconnect-Hook setzen
    nur noch ein Flag (per Task-Notify oder Lock); die eigentliche Arbeit
    läuft hier mit PSRAM-Stack (M2).
- Die esp_timer-Objekte entfallen.

## Reihenfolge

1. **Sofort, jeweils wenige Zeilen:** K2, K3, K1. Ohne K2 scheitert Stufe 2
   schon beim zweiten Testlauf.
2. Umbau A zusammen mit dem Mutex aus H2.
3. Umbau B, vor den Hörtests der Stufe 3, denn K4 verfälscht sonst genau den
   Test, auf dem die Architektur beruht.
4. Umbau C.
5. M3 nach dem ersten Hörtest; N1–N3 bei Gelegenheit.

## Auf Hardware zusätzlich prüfen

- **Interner Heap:** `min_ever` während einer Durchsage mit vielen Clients.
  UDP-pbufs liegen im internen DRAM (`CONFIG_SPIRAM_TRY_ALLOCATE_WIFI_LWIP`
  ist aus), dazu kommen N × 100 Pakete/s obendrauf.
- **Empfangsqueue des Servers:** `CONFIG_LWIP_UDP_RECVMBOX_SIZE=6` bei
  WLAN-Bursts vom Handy. Verworfene Pakete sind gewollt, aber die Rate ist
  interessant.
- **Server-Lautsprecher:** Er wird erst nach dem Fan-out gefüttert. Wenn
  `sendto()` langsam wird, lohnt es sich, die Reihenfolge zu tauschen.

## Android-App

Abgesehen von M5 und N3 keine Befunde. Es gilt aber: Die App ist ungebaut,
weil hier kein SDK installiert ist. Beim ersten Öffnen in Android Studio mit
Build-Fehlern durch Versionsstände rechnen (AGP 8.5 / Kotlin 1.9 / BOM
2024.06); die angebotenen Updates annehmen.

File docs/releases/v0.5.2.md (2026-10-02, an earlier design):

Bugfix-Release. Server **und** alle Clients aktualisieren.

## Behoben

* **Echo nach Zeitkorrekturen des Servers.** Der Server zieht seine Zeitachse in kleinen Schritten nach, wenn er Aufnahme
  verloren hat. Die Clients haben das erst ab 50 ms gesehen und sind dann jeder für sich gesprungen, teils Minuten
  auseinander. Jetzt prüfen sie jedes Paket genau und springen alle beim selben Paket.
* **Nach einem Sprung bis zu 20 ms daneben.** Ein Client hat in ganzen 20-ms-Blöcken gewartet und lag danach je nach
  Gerät unterschiedlich weit daneben. Jetzt wartet er auf das Sample genau.
* **Client lief nach dem Überspringen weg.** Dabei ging die Korrektur für seinen Quarz verloren, und er lag minutenlang
  30–40 ms daneben. Die Korrektur bleibt jetzt erhalten.
* **Klangbild wanderte zwischen den Lautsprechern.** Jeder Client hat die Uhr des Servers aus einer einzelnen Messung
  übernommen und ist alle paar Sekunden um einige ms gesprungen. Jetzt nimmt er eine Ausgleichsgerade über 64 s. Bei mir
  liegen die Clients damit unter 2–3 ms beieinander, vorher 5–8 ms.
* **Server verlor Aufnahme unter Last.** Die Firmware wird jetzt mit `-O2` statt `-Og` gebaut. Der Opus-Encoder braucht
  damit etwa 75 statt 90–97 % eines Kerns und hat mehr Luft, wenn nebenbei die Web-Seite läuft.
* **Aussetzer beim Verstellen am Server.** Jeder Schritt am Lautstärkeregler eines Clients wurde sofort in den Flash
  geschrieben, und das hält den ESP kurz an. Jetzt speichert der Server erst 3 s nach der letzten Änderung.

## Geändert

* Im Log stehen jetzt Leerlauf und Überlauf der I2S-Puffer und alle 30 s der Stand des Zeitabgleichs.
* Als I2S-Slave tastet der ESP die Takte mit 80 MHz ab und filtert Störspitzen auf BCLK und LRCLK.

## Update von v0.5.1

* Die meisten Korrekturen stecken in den Clients, `-O2` hilft vor allem dem Server. Aktualisiert deshalb alle Geräte.
* Mit den vier Einzeldateien bleiben die Einstellungen erhalten (Browser ohne „Erase device“ oder esptool, siehe
  unten).

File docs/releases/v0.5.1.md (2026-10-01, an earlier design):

Bugfix-Release. Server **und** alle Clients aktualisieren.

## Behoben

* **Echo zwischen Lautsprechern.** Verlor der Server Audio aus seiner Aufnahme, setzte er seine Zeitachse neu. Die
  Clients erkannten so einen Sprung erst ab 100 ms. Lag er knapp darüber, folgte ein Client und der nächste nicht.
  Dann liefen beide etwa 100 ms auseinander, oft minutenlang. Jetzt erkennen alle Clients einen Sprung ab 50 ms gleich
  und gleichen den Rest sofort aus.
* **Neuladen der Einstellungsseite des Servers störte die Wiedergabe.** Die Seite geht jetzt gzip-komprimiert raus
  (14 statt 49 KB, ein Aufruf dauert etwa 80 statt 300 ms). Kleine Abweichungen seiner Zeitachse zieht der Server
  jetzt langsam nach, statt zu springen. Mehrfaches Neuladen löst keinen Sprung mehr aus.
* **Hängende Verbindung zu einem Client.** Kam bei einem Client mehr als die Hälfte der Audiodaten nicht an, hakte es
  bis zu 100 s lang. Jetzt schließt der Server die Verbindung nach 3 s, und der Client verbindet sich neu.

## Geändert

* **Standardbelegung der Pins:** BCLK 12, LRCLK 14, DIN 11, DOUT 13, vorher 4/6/5/7. Die Vorlage für 4/6/5/7 ist
  entfallen, „Alternative 1“ heißt jetzt „Alternative“.
* Der Server meldet im Log, wenn seine Aufnahme zurückfällt oder eine Web-Anfrage lange dauert.

## Update von v0.5.0

* Die Echo-Korrektur steckt in den Clients, die anderen Korrekturen im Server. Aktualisiert deshalb alle Geräte.
* Mit den vier Einzeldateien bleiben die Einstellungen erhalten (Browser ohne „Erase device“ oder esptool, siehe
  unten).
* Die neue Standardbelegung gilt nur für Boards, die noch nie Pins gespeichert haben. Ist so ein Board auf 4/6/5/7
  verdrahtet, stellt diese Pins nach dem Update unter Pins ein, sonst bleibt es stumm.

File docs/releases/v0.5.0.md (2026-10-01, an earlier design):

## Neu

* **ESP als I2S-Slave.** Unter Pins → **I2S-Takt** wählt ihr, wer BCLK und LRCLK erzeugt: der ESP wie bisher oder
  ein externes Gerät, zum Beispiel ein DSP wie der ADAU1701. Dann laufen Quelle, DAC und ESP auf dessen Takt. Fehlt
  der Takt, bleibt es still, und das Log meldet es alle 5 s. Getestet mit einem ADAU1701 als Takt-Master.
* **Ein/Aus-Taster.** Ein Taster von einem freien GPIO (1–21) gegen GND, ohne weitere Bauteile. 2 s halten schaltet
  aus, drücken schaltet ein. Den Pin stellt ihr unter Pins ein. Aus heißt Deep Sleep: Nur der ESP schläft, DAC,
  Verstärker und Spannungsregler am Akku ziehen weiter Strom.
* **Lautstärke auf der Seite des Clients.** Schieber und Stumm, sofort wirksam, auch ohne Server und im
  Einrichtungs-AP. Solange ein Server verbunden ist, stellt er die Lautstärke ein, dann ist der Regler gesperrt.
* **DSP:** Subsonic-Hochpass im Sub, Sub-Phase 180°, Kompressor je Zweig (Schwelle, Verhältnis, Aufholen), Gains bis
  +18 dB. Am Ende beider Zweige sitzt ein Begrenzer bei −0,5 dBFS mit kurzer Vorausschau statt hartem Abschneiden.
  Während einer Durchsage sind Vorausschau und Kompressor aus. Das spart Latenz und hebt den Raum nicht an.
* **Potis:** Drehrichtung je Poti umkehrbar.
* **Web-UI auf Deutsch und Englisch,** je nach Browsersprache. Weiche und Kompressor wirken beim Ändern, ohne
  Speichern. Neue Pin-Vorlage „Alternative 2“ (BCLK 12, LRCLK 14, DIN 11, DOUT 13). Werkseinstellungen fragen auf der
  Seite nach.
* **App SnapAnnounce:** Englisch und Deutsch. Die Durchsage-AGC hat eine Rauschsperre: Pausen und Raumgeräusch werden
  nicht mehr hochgezogen. Das verhindert Rückkopplung, wenn die Anlage laut ist.

## Geändert

* **Puffer:** Es zählt nur noch der Wert am Server, er gilt für alle Geräte.
* **Feste Server-Adresse entfernt.** Der Server ist immer die Mesh-Root. Ein früher gespeicherter Wert wirkt nicht
  mehr.
* **Durchsagen** enden erst nach 1 s ohne Pakete statt nach 400 ms. Zwei Mesh-Ebenen tief zerfielen sie sonst in
  Stücke, dazwischen lief kurz Musik.
* **Web-UI:** Delay nur noch in der Geräteliste. Puffer nur am Server, Quelle und Schwelle nur am Client. Pins und
  Opus sind eingeklappt. Nach einem Update zeigt der Browser die neue Seite statt einer alten aus dem Cache.

## Behoben

* Ein Client im Einrichtungs-AP startete bei jeder Statusabfrage der Seite neu und nahm kein Speichern an.

## Doku

* README neu geschrieben und deutlich kürzer, dazu eine englische Fassung (README.en.md).
* Bauvorschlag SnapStreamer: Empfänger mit PCM5102A, Akku und Gehäuse. FreeCAD-Modell und 3MF zum Drucken liegen in
  `mechanics/housing`.
* Logo „Phasengleich“ in README, Flash-Seite und Web-UI.
* Jedem Release liegt `THIRD_PARTY_LICENSES.txt` mit den Lizenzen der Firmware-Komponenten bei.

## Update von v0.4.0

* Mit den vier Einzeldateien bleiben die Einstellungen erhalten (Browser ohne „Erase device“ oder esptool, siehe
  unten). Die neuen Einstellungen starten aus: kein Subsonic, Phase normal, Kompressor aus, Potis nicht umgekehrt, ESP
  als I2S-Master, kein Taster.
* Aktualisiert alle Geräte im Mesh, zuerst den Server. Die Einstellungsseite kommt immer von dem Gerät, das ihr
  aufruft. Über die Seite des Servers seht ihr die neuen Felder erst, wenn der Server aktualisiert ist, und setzen
  lassen sie sich nur bei Clients mit der neuen Firmware.

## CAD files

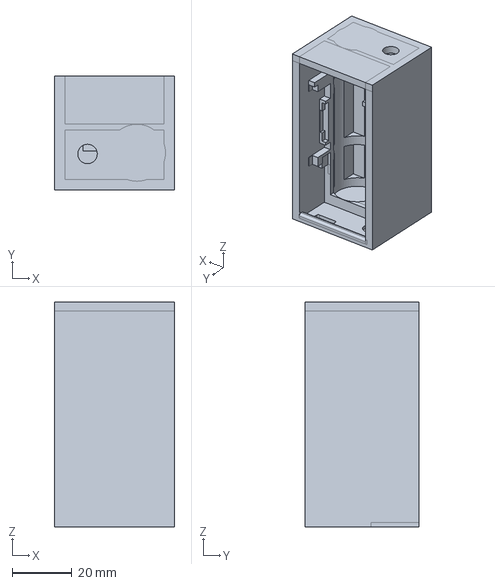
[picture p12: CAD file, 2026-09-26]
mechanics/housing/Snapstreamer2.FCStd
40.0 x 38.0 x 75.0 mm

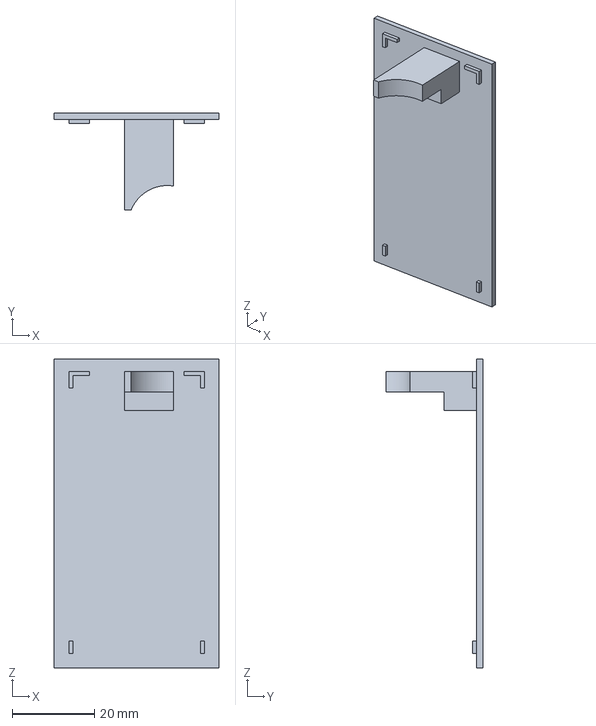
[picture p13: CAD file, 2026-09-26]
mechanics/housing/Snapstreamer2-SStreamer GoT.3mf
40.0 x 23.5 x 75.0 mm

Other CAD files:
mechanics/housing/Snapstreamer2-SStreamer GuT.3mf

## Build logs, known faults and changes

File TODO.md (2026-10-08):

# Bugfix-Backlog

## Offen, Stand 2026-10-07

Kurzliste; Einzelheiten in den Einträgen weiter unten.

- **Nächste Release-Notizen:** Slave-Takt 80 MHz und Glitch-Filter auf
  BCLK/LRCLK (in v0.5.2 als Änderung genannt) sind wieder ausgebaut,
  siehe „Knistern am 7788“. Der Ein/Aus-Taster schaltet erst nach 1 s
  Halten ein. Opus läuft mit Festkomma statt Gleitkomma.
- **Features:** OTA über die Web-Seite; USB-Audio (Server-Eingang,
  Client als Mikrofon); Erkennung, ob das Handy bei Durchsagen direkt am
  Root hängt.
- **Ein/Aus-Taster:** Ausstehende Client-Einstellungen (3 s verzögert
  gespeichert) gehen beim Ausschalten verloren; es fehlt ein Flush in
  `client_store` vor dem Deep Sleep.
- **Rechenzeit:** Encoder-Anstieg während Durchsagen; `tiT`/`wifi` auf
  Kern 0 während Durchsagen.
- **Durchsage:** Tests 1–5; `voice_dropped` (Mailbox-Größe);
  `docs/code-review-voice.md` nachziehen.
- **Mesh/Robustheit:** Relay mit mehreren Kindern; hängender Zweig am
  Server; Einbruch beim Abgang eines Clients; `SNAPSERVER_MAX_CLIENTS = 10`
  ungetestet; Fusion-Intervall und Reconnect-Intervall beobachten;
  Aussetzer beim Beitritt eines Clients.
- **Messung:** Versatz Server ↔ Clients an den Lautsprechern;
  `audio_i2s_clock_ppm()` reparieren oder entfernen.
- **Aufräumen:** Diagnose-Code (`cpu_stats.c`, `heap … children=`,
  Decodierzeit) behalten oder entfernen; Screenshots in `docs/`.
- **Auf Hardware nicht abgehakt:** Root-Wächter im Client (Server bei
  laufenden Clients ausschalten); Ein/Aus-Taster mit 1 s Halten;
  Pin-Seite, App-Geräteliste, Provisioning (Stufe 5), Board mit weniger
  als 16 MB Flash.

## Code-Analyse und Stufen 1–6

Aus einer Code-Analyse (2026-09-16) auf `test/fixup`. Alle identifizierten
Bugs sind umgesetzt:

- Stufe 1: Client-Slot-Leak durch fehlenden Recv-Timeout/Keepalive
  (Commit 151007f)
- Stufe 2: Unsynchronisierter 64-Bit-Zugriff auf die Zeitbasis + tote
  Kconfig-Option `SNAPSERVER_MESH_ROOT_ONLY` (Commit 585758d)
- Stufe 3: Race bei `client->peer` beim Slot-Recycling (Commit 7d6fb86)
- Stufe 4 (aus Live-Log 2026-09-17 gefunden): `audio_task` versendet
  Wire-Chunks synchron und blockierend an jeden Client nacheinander
  (`SO_SNDTIMEO`=2s). Ein einzelner langsamer/überlasteter Client konnte die
  I2S-Capture-Pipeline dadurch für alle Clients bis zu mehrere Sekunden
  blockieren (im Log bis 2,6s Drift beobachtet). Fix: Vor jedem Send prüft
  `client_socket_writable()` per Zero-Timeout-`select()`, ob der Socket
  aktuell beschreibbar ist; falls nicht, wird der Chunk für diesen Client
  übersprungen (`chunks_skipped`-Zähler) statt die Pipeline zu blockieren.
  Auf dem Gerät verifiziert: keine Drift-Warnungen mehr bei parallel
  belastetem Client.
- Stufe 5 (Code-Review auf `test/provisioning`, 2026-09-17, Effort `high`,
  12 Befunde): Passwort-Leak bei 1-7-Zeichen-Mesh-Passwort (offener AP,
  aber `/api/config` gab das Passwort weiterhin heraus); Config-Server
  konnte durch einen hängenden POST dauerhaft blockiert werden
  (`esp_http_server` ist single-threaded); Build brach bei
  `SNAPSERVER_ENABLE_MESH_LITE=n` (zwei verschiedene Ursachen: abhängige
  Kconfig-Symbole existieren nicht, und ein bool-Kconfig-Symbol ist bei `n`
  gar nicht definiert, nicht `0` — beides in `device_config.c` gefixt und
  mit `idf.py build` bei deaktiviertem Mesh gegengeprüft); SSID-Länge bei
  genau 32 Zeichen falsch berechnet (`strlcpy`-Ziel vs. Quelle); NVS-Writes
  im knapp bemessenen `esp_timer`-Task-Stack statt eigenem Task;
  `device_config_t`-Cache ohne Synchronisation zwischen HTTP- und
  Timer-Task; Factory-Reset konnte durch einen noch laufenden
  Grace-Window-Write still rückgängig gemacht werden; `schedule_reboot()`
  konnte einen NULL-Timer starten; Config-Seite startete erst nach
  Audio-Init (bei Audio-Fehler nie erreichbar); dazu zwei
  Design-Entscheidungen: Provisioning-AP rebootet nicht mehr nach 3 Minuten
  (schaltet nur noch den Funk ab, Wiedereinstieg nur per Power-Cycle oder
  Save), und ein Save während aktivem Provisioning-AP rebootet jetzt immer.
  Auf dem Gerät verifiziert: normaler Mesh-Boot ohne Regression, Config-Web-
  server startet jetzt vor Audio-Init. Nicht auf dem Gerät verifizierbar
  (damals kein WLAN-fähiges Zweitgerät verfügbar): Passwort-
  Ablehnung <8 Zeichen per curl, 32-Zeichen-SSID im WLAN-Scan, volles
  3-Minuten-Timeout-ohne-Reboot-Fenster, Stresstest paralleler Saves
  während des Grace-Windows — siehe Plan-Datei für den vollständigen
  Verifikationsplan.

- Stufe 6 (Feature auf `test/ServerClient`, Plan aus Analyse der Client-Rolle
  und des Referenzprojekts `ESP32_Mesh_Snapclient`, Stufe 1 von 2): der
  ESP32-S3 kann nun per NVS-Feld `role` wahlweise als Server (Mesh-Root, wie
  bisher) oder als Client (Mesh-Non-Root-Relay, Snapcast-Empfang) booten,
  umschaltbar über die Web-Config-Seite, Übernahme per Reboot. Neu:
  `mesh_client.c` (Non-Root-Join, nie Leaf — ein Leaf könnte in der
  schlauchförmigen Zieltopologie keine Kinder annehmen; Server-Adresse über
  `esp_mesh_lite_get_root_ip()`, da lokales DHCP-Gateway ab Level 3 nur den
  Elternknoten liefert und mDNS die NAPT-Grenze zwischen den Ebenen nicht
  überquert), `snapclient.c` (Snapcast-Protokoll, portiert aus dem
  Referenzprojekt, aber ohne A2DP/Bluetooth — der ESP32-S3 hat kein
  Bluetooth Classic — und mit tatsächlicher Auswertung von Rate/Kanälen aus
  dem CodecHeader statt hartcodiertem Stereo, da unser eigener Server mono
  sendet), `audio_sink.c` (Quellen-Arbiter zwischen Netzwerk-Audio und
  lokalem I2S-Eingang als Ersatz für die A2DP-Priorität der Referenz,
  PSRAM-Ringpuffer). `audio_i2s.c` wurde dafür in Capture- und
  DSP+Ausgabe-Hälfte aufgetrennt (`audio_i2s_capture_mono()`/
  `audio_i2s_write_mono()`), ohne das bestehende Server-Verhalten zu ändern.
  `bufferMs` ist jetzt konfigurierbar statt hart 1000 (Server sendet den
  Wert aus `device_config`, Client dimensioniert seinen Ringpuffer danach).
  Auf dem Gerät verifiziert: Build sauber, sowohl mit
  `CONFIG_SNAPSERVER_ENABLE_MESH_LITE=y` als auch `=n`. Nicht verifiziert
  (damals kein zweites WLAN-fähiges Testgerät verfügbar):
  tatsächlicher Mesh-Join als Non-Root, Snapcast-Wiedergabe, automatische
  Quellenumschaltung auf den lokalen Eingang, Rollenwechsel per Reboot.
  Stufe 2 (noch offen): Zeit-Sync (`SNAP_MSG_TIME`) und Drift-Kompensation,
  damit mehrere Clients über Stunden synchron bleiben — siehe Plan-Datei.

## Nicht als Bug, aber vorgemerkt

- **Knistern am 7788 als I2S-Slave eines ADAU1701 (2026-10-02; vorerst als
  gelöst betrachtet 2026-10-07, bei Bedarf neu aufmachen).** 7788 bekommt
  BCLK/LRCLK vom ADAU1701 und knisterte mehrmals pro Minute; 14E4 spielte
  denselben Stream sauber. Gemessen: stummgeschaltet kein Knistern; leiser
  gedreht bleiben die Klicks gleich laut, also kein Clipping. Die ESP-Seite
  lieferte lückenlos (Zähler für TX-Leerlauf 0, keine Sprünge, kein
  Unterlauf im Ring). Ohne hörbare Wirkung versucht: DOUT mit 5 mA
  (sofort zurückgenommen), Slave-Takt 80 MHz statt 24,576 MHz und
  Glitch-Filter auf BCLK/LRCLK (8505ab4, ausgebaut 2026-10-07; die
  DMA-Zähler aus demselben Commit bleiben). Nicht mehr geprüft: Format des
  Serial Ports in SigmaStudio (I2S, BCLK 64 fs), Clipping im DSP-Programm,
  Serienwiderstände 33–47 Ω, Masse, Betrieb ohne USB-Isolator.

- **Durchsage: Rechenzeit vor dem USB-Eingang klären (vorgemerkt
  2026-09-30).** Reihenfolge: erst die beiden Kern-Punkte, dann NVS, dann
  USB.
  1. **Reserve auf Kern 1 bei Durchsagen.** Die Komplexität des
     Musik-Encoders sinkt während einer Durchsage schon auf 0
     (`VOICE_MUSIC_COMPLEXITY` in `voice_announce.c`). Seit 2026-09-29
     kosten Begrenzer-Vorausschau und Kompressor auf Kern 1 zusätzlich etwa
     8 Prozentpunkte (14E4 als Client: `audio_sink` 44 → 52 %). Seit dem
     Build mit `-O2` (9fcced3, 2026-10-02) braucht der Encoder laut
     v0.5.2 etwa 75 statt 90–97 % eines Kerns.

     **Festkomma statt Gleitkomma (umgestellt 2026-10-08).** Gemessen auf
     BDFC mit einem vorübergehenden Benchmark: 250 Frames à 20 ms, festes
     Testsignal (Akkord, Sweep, leises Rauschen), Einstellungen wie im
     Server, eigener Task auf Kern 1 vor dem Start von WLAN und Audio.

     | Messung | Gleitkomma | Festkomma |
     |---|---|---|
     | Encode Musik c=5, 96 kbit/s | 9412 µs | 8787 µs (−6,6 %) |
     | Encode Musik c=0 (Durchsage) | 6807 µs | 5466 µs (−19,7 %) |
     | Decode Musik 48 kHz (Clients) | 3593 µs | 3309 µs (−7,9 %) |
     | Decode Sprache 16 kHz → 48 kHz | 2788 µs | 1173 µs (−58 %) |

     Während einer Durchsage (Encode c=0 plus Decode Sprache) sind das
     zusammen 47,9 statt 33,2 % von Kern 1; den echten Durchsagebetrieb
     habe ich danach nicht gemessen. `opus_audio` im Betrieb auf BDFC:
     38,6 → 36,7 %, mit dem Signal, das dort gerade am Eingang lag. Das
     Image ist 31 kB kleiner. Den Klang habe ich noch nicht verglichen.
  2. **Anstieg von tiT/wifi auf Kern 0 bei Durchsagen verstehen.** Drei
     UDP-Ströme mit je ~25 kbit/s erklären ihn nicht. Verdacht: viele kleine
     Pakete, Retransmits oder das Mesh-Relay. Messen (Pakete je Sekunde,
     Retransmits), bevor Kern 0 weitere Aufgaben bekommt.
  3. **NVS-Schreibzugriffe in `client_store` entprellen (erledigt
     2026-10-02, 3b60e7f).** Der Server schreibt erst 3 s nach der letzten
     Änderung, in eigenem Task. Vorher stand die Aufnahmeschleife bei jedem
     Schritt eines Lautstärke-Sliders 53 ms, bei 40 ms I2S-Puffer.
  4. **USB-Audio, je Rolle eine Richtung, kein Duplex auf einem Gerät.**
     - Server: USB als **Eingang** (UAC2-Wiedergabe vom PC), Feedback-Endpoint
       auf dem I2S-Takt, Jitter-Puffer im PSRAM, USB-Task auf Kern 0.
       Quellenwahl USB / I2S, etwa automatisch nach Aktivität.
     - Client: USB als **Ausgang**, der Client ist USB-*Gerät* (UAC2-Aufnahme):
       ein PC am Client bekommt den synchronen Mesh-Ton als Mikrofon. Takt
       einfach, die Aufnahme läuft im geregelten I2S-Takt des Clients.
       Nicht gemeint: Client als USB-Host für einen USB-DAC (Takt vom DAC,
       `usb_host_uac` meist nur UAC 1.0, deutlich aufwendiger).
     - Der native USB-Port gehört dann dem Audio; Log und Flashen über die
       COM-Buchse (CH343) der YD-Boards.
     - NVS: Die UAC2-Lautstärke vom PC nicht speichern (der PC setzt sie
       beim Verbinden neu) oder nur nach Ruhezeit. Grund neben dem
       Verschleiß: Jeder Flash-Schreib- oder Löschvorgang schaltet den Cache
       ab, Code im Flash und das PSRAM (Jitter-Puffer) stehen dann bis zu
       einige zehn ms. Deshalb Punkt 3 vorher, USB-Interrupts im IRAM, und
       den Jitter-Puffer so groß, dass er einen Schreibvorgang überbrückt.

- **Ein/Aus-Taster als Soft-Off per Deep Sleep (vorgemerkt 2026-09-30,
  umgesetzt 2026-10-01, 4ba38ce).** Taster an einem RTC-fähigen Pin
  (GPIO 1–21) gegen GND, wählbar auf der Pin-Seite. 2 s halten = aus: LED
  dunkel, DOUT auf LOW gehalten (als Master auch BCLK/LRCLK), nach dem
  Loslassen Deep Sleep. Grenze: Der Chip braucht im Deep Sleep µA, das
  Board nicht -- LDO, Power-LED, WS2812 (~1 mA auch dunkel), PCM5102A und
  CH343 ziehen weiter einige mA. Echtes Aus bleibt der Schalter am Poti.

  Einschalten erst nach 1 s Halten (2026-10-08, auf Hardware noch nicht
  getestet). Bis dahin weckte jeder Druck, ein Stoß in der Tasche schaltete
  das Gerät ein. Jetzt prüft `power_button_boot()` als Erstes in
  `app_main`, ob der Taster 1 s unten bleibt; sonst geht der ESP sofort
  wieder schlafen, ohne NVS anzufassen und ohne die gehaltenen Pins
  freizugeben. Zu prüfen: kurzer Druck bleibt aus, 1 s Halten schaltet
  ein, Halten bis über 2 s schaltet danach nicht gleich wieder aus.
  **Offen:**
  `power_button.c` sichert keine ausstehenden NVS-Schreibvorgänge.
  `client_store` schreibt seit 3b60e7f erst 3 s nach der letzten Änderung
  und hat keine Flush-Funktion; wer den Server in diesen 3 s ausschaltet,
  verliert die letzte Änderung.

- **Pinbelegung und Geräteliste (2026-09-23), auf dem Gerät noch nicht
  getestet.** Gebaut mit IDF 5.4.3, die Webseite gegen eine nachgebaute API
  geprüft (jsdom). Auf Hardware zu prüfen: Update eines bestehenden Geräts
  ändert keine Pins; Pinwechsel samt Neustart; Probestart-Rückfall nach drei
  missglückten Starts (z. B. absichtlich mit `abort()` nach
  `audio_i2s_start()`); Hops bei einem Client auf Ebene 3; Lautstärke/Delay
  überleben einen Reconnect und einen Server-Neustart. Die Screenshots in
  `docs/` zeigen noch die alte Seite.

- **Nächste Schritte dazu:** (1) Geräteliste in der Android-App — die Daten
  stehen schon in `Server.GetStatus` (`snapmesh.hops`), Änderungen kommen
  als `Server.OnUpdate`. (2) **Erledigt 2026-09-23, auf dem Gerät noch
  nicht getestet:** Pinbelegung und übrige Einstellungen eines Clients vom
  Server aus ändern. Kein eigener Steuerkanal nötig: Der Server schickt die
  Anfrage als eigenen Nachrichtentyp (100) über die Snapcast-Verbindung, die
  der Client ohnehin zum Root aufbaut und die deshalb durchs NAT geht
  (`snapserver_remote_request()`, beantwortet von
  `webconfig_handle_remote_request()`). Die Seite gegen eine nachgebaute API
  geprüft (jsdom). Auf Hardware zu prüfen: Werte eines Clients laden und
  speichern, Neustart nach Pinwechsel samt Neuladen, Client auf Ebene 3.

- **Client-Konfiguration auch in der App (erledigt 2026-09-23, auf dem Handy
  noch nicht getestet).** Mischform: Tab „Geräte" mit nativer Liste
  (Lautstärke, Mute, Delay, Name über `/api/devices`), die vollständigen
  Einstellungen eines Geräts als eingebettete Firmware-Seite
  (`/?device=<id>&embed=1`), damit Formular und Pin-Logik nur an einer
  Stelle gepflegt werden. Zu prüfen: Erreichbarkeit mit aktiven mobilen
  Daten (Prozessbindung ans WLAN), WebView-Dialog beim Factory Reset,
  Delay-Knöpfe auf schmalen Displays.

- **Unkomplizierte Verteilung (umgesetzt 2026-09-23, läuft seit v0.2.0;
  zuletzt v0.5.3 am 2026-10-02 mit Firmware-Teilen, Gesamt-Image, APK und
  `THIRD_PARTY_LICENSES.txt`).** `.github/workflows/release.yml` baut bei
  einem Tag `v*` Firmware (`espressif/esp-idf-ci-action`, IDF 5.4.3, nur
  aus `sdkconfig.defaults`) und das signierte APK, hängt beides an das
  GitHub-Release und stellt die Flash-Seite (`flasher/`, ESP Web Tools)
  auf GitHub Pages. Ein manueller Lauf baut nur, als Probe vor dem Tag.
  - **Updates schreiben vier Teile** (Bootloader `0x0`, Partitionstabelle
    `0x8000`, App `0x10000`, leeres `otadata` `0x3D0000`). Das Gesamt-Image
    aus `merge_bin` füllt
    `0x9000–0xFFFF` mit `0xFF` und löscht damit NVS und PHY-Daten; es ist
    nur für Neuinstallationen gedacht (geprüft 2026-09-23).
  - `sdkconfig.defaults` ergibt jetzt exakt das `sdkconfig` der Geräte
    (frischer Klon, 0 Abweichungen). Wer eine Option per `menuconfig`
    ändert, muss sie dort nachtragen, sonst baut CI etwas anderes.
  - Der Keystore der App liegt bei mir und als Secret in GitHub; geht
    er verloren, lässt sich die App nur noch per Deinstallieren updaten.
  - Offen: OTA über die Web-Oberfläche. Braucht OTA-Partitionen (siehe
    nächster Punkt) und einmal ein komplettes Neuflashen mit Löschen.
    Später denkbar: F-Droid oder Play Store.

- **Firmware auch auf Boards mit weniger Flash (umgesetzt 2026-09-24; läuft
  auf den 16-MB-Boards, ein Board mit 4 oder 8 MB Flash ist ungetestet).**
  Image-Header auf 4 MB
  (`CONFIG_ESPTOOLPY_FLASHSIZE_4MB`), `partitions.csv` passt in 4 MB. Dasselbe
  Image läuft damit auf N8R8 und N16R8. ESP-IDF bricht nur ab, wenn der Chip
  *kleiner* ist als der Header (`esp_flash_spi_init.c`); ein größerer bleibt
  ungenutzt. `nvs` (`0x9000`) und `phy_init` (`0xF000`) liegen unverändert,
  deshalb ist **kein Löschen** nötig: Ein Board mit dem alten 16-MB-Layout
  behält beim Update seine Einstellungen, solange `otadata` leer mitgeschrieben
  wird. Sonst läge dort ein Rest der alten App, und der Bootloader müsste ihn
  als ungültig verwerfen. Zu prüfen auf einem Board mit altem Layout:
  Start aus `ota_0`, `Config loaded from NVS`, Pins unverändert. Octal-PSRAM
  bleibt Voraussetzung; Quad-PSRAM (N8R2/N16R2) bräuchte eine zweite Variante
  mit `SPIRAM_MODE_QUAD`.

- **OTA über die Web-Seite (offen).** Die Partitionen sind seit 2026-09-24
  vorbereitet (`ota_0`/`ota_1` je 1,875 MB, `otadata`), es fehlt der Teil in
  der Firmware: Upload-Route in `webconfig.c` (`esp_ota_begin/write/end`,
  `esp_ota_set_boot_partition`), ein Feld auf der Seite, für Clients der Weg
  über den Server, und am besten Rollback (`CONFIG_BOOTLOADER_APP_ROLLBACK_ENABLE`,
  bestätigen wie bei `device_config_confirm_pins()`). Achtung: Nach einem
  OTA-Update startet das Board aus `ota_1`; der Browser-Flasher schreibt die
  App nach `ota_0` und setzt `otadata` zurück, das passt also weiter.
  Keine Coredump-Partition; in den 184 KB hinter `otadata` wäre Platz dafür.

- **Lautstärke der Quelle wirkt auf alle Clients gemeinsam (gemeldet
  2026-09-17):** Wird am A2DP-Gerät, das den I2S-Eingang des Servers
  speist, die Lautstärke verändert, ändert sich der Pegel für sämtliche
  Clients gleichzeitig. Das ist derzeit systembedingt und kein Fehler im
  engeren Sinn: Die Regelung sitzt **vor** der Aufnahme, der Server
  encodiert also bereits das abgesenkte Signal, und jeder Client bekommt
  es so. Zwei Konsequenzen daraus, die zusammen gehören:
  1. **Erledigt 2026-09-18:** Das Snapcast-Protokoll hat eine Lautstärke
     **pro Client**, die der Server bereits verwaltet
     (`client->volume_percent`, über `Client.SetVolume` der JSON-RPC in
     `snapcontrol.c`) und nach jeder Änderung erneut in den ServerSettings
     annonciert. Der Client wertet `volume`/`muted` jetzt aus und wendet
     sie an. Die Kette ist damit über eine Snapcast-Control-App komplett
     bedienbar. Angewendet wird am Ende des Wiedergabepfads, nicht beim
     Einspeisen — sonst wäre der Pegel im Ringpuffer eingebacken und eine
     Änderung erst `buffer_ms` später hörbar. Die Kennlinie ist kubisch
     (perzeptive Näherung, sonst drängt sich der ganze nutzbare Bereich
     ins obere Ende des Reglers); falls sie in der Praxis zu steil wirkt,
     ist sie in `audio_sink_set_volume()` mit einer Zeile zu ändern.
  2. **Bleibt offen:** Damit das etwas nützt, muss die Quelle auf
     konstantem Pegel bleiben (A2DP-Lautstärke voll aufdrehen und nicht
     mehr anfassen), sonst multipliziert sich beides. Den Pegel der Quelle
     zurückzurechnen geht ohne Rückkanal vom A2DP-Empfänger nicht sauber.
  3. **Erledigt 2026-09-23:** Die Geräteliste oben auf der Server-Seite
     stellt Lautstärke, Stummschaltung und Delay pro Client ein.
  4. **Erledigt 2026-09-23:** Lautstärke, Stummschaltung, Latenz und ein
     vergebener Name werden pro Client-ID im NVS gehalten
     (`client_store.c`, bis 24 Clients, danach fällt der am längsten nicht
     geänderte heraus) und bei jedem Hello wieder eingespielt.

- **Clients im laufenden Mesh konfigurieren (gemeldet 2026-09-17):** Aktuell
  ist unklar dokumentiert, wie man an die Config-Seite eines Clients kommt,
  der bereits im Mesh hängt. Beim Durchsehen der Logs zeigt sich, dass der
  Fall einfacher liegt als früher in diesem Projekt angenommen, aber nur
  für die erste Ebene:
  - Ein Client, der direkt am Root hängt, bekommt seine STA-Adresse aus dem
    DHCP des Roots und liegt damit im **selben** Subnetz wie ein Handy, das
    sich mit dem Root-AP verbindet (im Log: Root-AP `192.168.5.1`, Client
    `192.168.5.2`). Dazwischen liegt kein NAT — `http://192.168.5.2/`
    sollte also bereits heute funktionieren. Das ist ungetestet und wäre
    als Erstes zu verifizieren, weil es ohne jede Codeänderung auskäme.
  - Ab Ebene 3 greift die NAT-Schachtelung von `esp_bridge` wieder: ein
    Enkelknoten liegt hinter dem NAT seines Elternknotens und ist von oben
    nicht adressierbar.
  - Es fehlt in jedem Fall die Auffindbarkeit — welche IP gehört zu welchem
    Gerät. Der Server kennt das bereits (`client[i]`-Statuszeile mit IP und
    Hostname aus dem Hello) und könnte es auf seiner Config-Seite als Liste
    mit Links anzeigen. Das wäre der kleinste sinnvolle Schritt.
  - Für tiefere Ebenen bliebe ein Proxy über den Server (Weiterleitung an
    einen ausgewählten Knoten über die Mesh-Lite-interne Verbindung) — das
    ist deutlich aufwendiger und sollte erst geplant werden, wenn die
    Topologie wirklich mehr als zwei Ebenen hat.
  - **Stand 2026-09-23:** Erledigt ohne Proxy über Mesh-Lite: „Settings"
    in der Geräteliste zeigt die Einstellungen eines Clients auf der
    Server-Seite, der Weg läuft über dessen Snapcast-Verbindung (siehe
    „Nächste Schritte dazu" oben). Die IP-Links sind entfallen.

- **Root-Failover-Risiko im Client-Modus (aus Analysegespräch 2026-09-17;
  Wächter umgesetzt 2026-10-08, auf Hardware noch nicht getestet):**
  `esp_mesh_lite_set_disallowed_level(1)` in `mesh_client.c` schließt den
  Client beim regulären Beitritt sicher von der Root-Rolle aus
  (API-Vertrag, keine Timeout-basierte Übernahme). Die Mesh-Lite-Doku
  beschreibt aber einen separaten Selbstheilungspfad bei
  Root-Ausfall ("Root Node Failure"), bei dem ein Kind-Knoten nach
  mehreren fehlgeschlagenen Reconnect-Versuchen selbst Root werden kann —
  dort beschrieben für den Router-verbundenen Modus ("connect directly to
  the router"), was auf unser No-Router-Setup (Client hat keine
  Router-Config) vermutlich nicht direkt zutrifft. `esp_mesh_lite_core`
  liegt nur als vorkompilierte `.a` vor (`lib/libesp_mesh_lite_esp32s3.a`),
  daher nicht quellcodeseitig verifizierbar, ob `disallowed_level` auch in
  diesem Pfad greift. Ich stufe das Risiko als kritisch ein: würde
  der Client dennoch Root werden, kollidiert er mit dem echten Server-Root
  und bleibt es dauerhaft, da nichts in unserem eigenen Code den
  Mesh-Level nach dem Boot überprüft.

  Vorgeschlagene Absicherung (2026-09-17, umgesetzt mit Neustart statt
  `esp_wifi_stop()`, siehe unten):
  periodischer Wächter in `mesh_client.c`, der `esp_mesh_lite_get_level()`
  zyklisch abfragt und bei Level 1 sofort `esp_wifi_stop()` auslöst
  (gleiches Muster wie der Provisioning-AP-Timeout) statt den Client
  stillschweigend als Root weiterlaufen zu lassen.

  Pflicht-Testszenario vor Stufe 2: Server im laufenden Betrieb
  ausschalten, während ein Client verbunden ist, und das Client-Log
  beobachten — bisher ungetestet.

  **Stand 2026-10-07, Doku von Mesh-Lite 1.0.2 nachgelesen:** Drei
  Stellen sprechen dafür, dass der Fall nicht eintritt, belegt ist es
  weiterhin nicht. (1) `User_Guide.md`, Abschnitt „Root Node Failure“:
  „If all nodes except the disconnected root node are not allowed to be
  Level 1, self-healing cannot be performed.“ Das ist unser Aufbau. (2)
  `CHANGELOG.md` zu 1.0.2: „The device disallowed as root node will not
  request to be included in the will list“, also nicht in die Liste der
  Root-Kandidaten. (3) Espressifs Beispiel `no_router` trennt Root und
  Kinder genau wie wir (`set_allowed_level(1)` / `set_disallowed_level(1)`).
  Ein Server-Neustart bei laufenden Clients kam seitdem oft vor; ein
  Client als Root ist dabei nicht aufgefallen, gezielt geprüft wurde es
  aber nie. Zur Reaktion des Wächters: `esp_wifi_stop()` lässt den Client
  bis zum Aus- und Einschalten stumm, auch wenn der Server nach Sekunden
  zurück ist. Die Alternative ist ein Neustart, dann begrenzt auf einen
  pro Minute, damit keine Schleife entsteht.

  **Umgesetzt 2026-10-08:** `root_guard_cb()` in `mesh_client.c` fragt
  jede Sekunde `esp_mesh_lite_get_level()` ab. Steht der Client 5 s am
  Stück auf Level 1, startet er neu und tritt wieder als Relay bei,
  frühestens 60 s nach dem Start; so startet er höchstens einmal pro
  Minute neu. Spielt er gerade seinen lokalen I2S-Eingang, startet er
  nicht neu, sondern erst 60 s nach dessen Ende; startet der Eingang in
  dieser Zeit wieder, beginnen die 60 s nach seinem nächsten Ende von
  vorn. Jeder Wechsel des Levels steht im Log (`Mesh level …`).
  Test: Server ausschalten, während mehrere Clients laufen, und deren Logs
  1–2 min mitschneiden. Die Zeilen zeigen dann auch, welchen Level ein
  Knoten ohne Parent meldet. Das ist nicht bekannt; meldet er dabei 1,
  startet jeder Client ohne Server einmal pro Minute neu, und der Wächter
  muss anders prüfen.

- Stufe 6 Nachbesserungen (erster echter Zwei-Geräte-Test auf `test/
  ServerClient`, 2026-09-17): vier Bugs beim tatsächlichen Betrieb
  gefunden und gefixt: (1) `esp_mesh_lite_get_root_ip()` liefert die IP
  mit vertauschter Byte-Reihenfolge zurück (`192.168.5.1` kam als
  `1.5.168.192` an) — Client fand den Server dadurch nie; Fix per
  `__builtin_bswap32()` in `mesh_client.c`. (2) Jeder Client hatte eine
  eigene, MAC-suffigierte SSID (`SnapMesh_XXXXXX`), was bei mehreren
  Clients zu SSID-Wildwuchs führte; Mesh-Lite erkennt Eltern-Knoten aber
  über eine Vendor-IE-Kennung im Beacon, nicht über den SSID-Text, daher
  jetzt einheitliche SSID (identisch zum Server) für alle Rollen. (3)
  Jedes Gerät (Server und alle Clients) meldete denselben mDNS-Namen
  `snapserver.local`, wodurch DNS/mDNS-Caches beim Wechsel zwischen
  Geräten auf der falschen Config-Seite landen konnten; jetzt eindeutiger
  Name pro Rolle+MAC (`snapserver-XXXXXX`/`snapclient-XXXXXX`). (4) Der
  Server trennt einen Client nach 30s Funkstille von dessen Seite
  (`CLIENT_RECV_TIMEOUT_US`, gedacht um tote Verbindungen zu erkennen) —
  unser eigener Snapclient sendet aber (Zeit-Sync ist ja erst Stufe 2)
  nichts zurück und wurde dadurch zuverlässig alle ~31s getrennt; Fix:
  `snapclient.c` sendet jetzt alle 2s eine leere `SNAP_MSG_TIME`-Anfrage
  rein als Herzschlag (Antwort wird ignoriert). Zusätzlich fiel auf, dass
  der Ringpuffer trotz `buffer_ms=3000` in der Praxis nur 40-120ms Füllstand
  hielt, weil `audio_sink.c` sofort bei der ersten eintreffenden
  Netzwerk-Anfrage umschaltete statt erst ein Polster aufzubauen — jede
  kleine Timing-Schwankung erzeugte dadurch einen hörbaren Underrun; Fix:
  Umschalten auf Netzwerkquelle erst ab 80% Füllstand
  (`NETWORK_PREBUFFER_PERCENT`), spätere Einbrüche lösen kein erneutes
  Prebuffering mehr aus.

  Auf dem Gerät verifiziert: Client verbindet nach den Fixes zuverlässig
  zum Server, Ringpuffer füllt sich wie erwartet, `output_rms`-Log
  bestätigt echtes Signal am Ausgang. Nicht behoben: deutliches Knistern
  im Audio, das bei mir auch am **Server** selbst auftritt (dort ohne
  jede Code-/HW-Änderung an diesem Pfad) und nur bei aktivem Stream zu
  hören ist, nicht bei Stille — daher software-, nicht hardwarebedingt.
  Klingt nach ca. einer Minute Laufzeit spürbar ab. Ursache nicht
  identifiziert, von mir zurückgestellt statt weiter untersucht.

  **Wieder aufgetreten 2026-09-23:** nach einem Flash des Servers (19:43)
  knackten Server-Lautsprecher und alle Clients, auch der Android-Snapclient,
  über Minuten, ohne abzuklingen. Quelle war ein iPhone per A2DP am TinySine,
  beides lief unverändert weiter; ein Neustart aller ESPs (19:48) hat es
  beseitigt. Die Server-Statistik war in beiden Zuständen unauffällig
  (~52 Chunks/s je Client, `skipped=0`, Frame-Abstand 20 ms ± 6 ms,
  I2S-Takt < 150 ppm, 84 kB interner Heap frei). Es hängt also an einem
  Zustand, den der Server beim Start einnimmt, nicht an Quelle, Funk oder
  Last. Nächster Schritt, wenn es wieder auftritt: Uhrzeit notieren und den
  Server-Log um diesen Start herum mit einem sauberen Start vergleichen.

  **Vorerst als gelöst betrachtet (2026-10-07), bei Bedarf neu aufmachen.**
  Die Artefakte vom 2026-09-20 mit ähnlichem Bild waren Fehler A (unten).

  **Stand 2026-09-24 -- mehrere unabhängige Fehler um den TinySine:**
  - *Stream und A2DP überlagert (geklärt):* Auf dem Android lief die
    Snapcast-App im Hintergrund und spielte den Stream per Bluetooth in den
    TinySine. Die Firmware gab nachweislich nur den lokalen Eingang aus;
    nach Beenden der App war es weg. Kein Firmwarefehler.
  - *A -- nur A2DP gestört, zeitweise (behoben 2026-09-25 mit
    Pegelwandler):* **Ursache: der TinySine AudioB I2S V2r0 arbeitet mit
    1,8 V I2S-Pegel** (gemessen; der ESP32-S3 braucht für High laut
    Datenblatt 0,75 x 3,3 V = 2,5 V). Der ESP tastete DIN damit zu knapp
    an der Flanke ab: je nach Start, und auch mitten im Betrieb, kippten
    Bits -- mal wenige in den unteren Bits, mal Zehntausende je 5 s. Der
    ADAU1701 kam mit dem Pegel zurecht. **Abhilfe: TXB0104 zwischen
    TinySine und ESP** -- VCCA 1,8 V (TinySine-Seite), VCCB 3,3 V, OE an
    VCCA, A1/B1 BCK, A2/B2 LRCK, A3/B3 SD, A4 an GND; der PCM5102A bleibt
    direkt am ESP. Jeder TinySine braucht einen solchen Wandler. Der
    ISO1540 taugt nicht (I2C-Isolator, Open-Drain, max. 1 MHz).
    Belege (Testton 1 kHz, Sinus-Vorhersage: jedes Sample aus den beiden
    vorherigen, Abweichung > 1024 = Fehler; Testfirmware nicht committet):
    B6:88 ohne Wandler 3 von 9 Starts gestört (4-22 s lang), mit Wandler
    0 von 16; 14:E4 mit Wandler 0 von 8.
    Verworfene Ansätze: 24-Bit-Slots/2,304 MHz (der erste Versuch lief mit
    MCLK 256 x fs bei 51,2 kHz statt 48 kHz, der zweite mit 384 x fs korrekt
    -- Fehler unverändert); weichere Taktflanken (GPIO_DRIVE_CAP_0 an
    BCLK/LRCLK: jeder Start gestört). Die DIN-Abtastverzögerung
    (`I2S_RX_TIMING_REG.rx_sd_in_dm`, 1 = eine Flanke später) beendete am
    Server jede Störphase innerhalb von 20-40 ms, war an 14:E4 aber in
    einzelnen Phasen selbst gestört -- ohne Wandler nur eine Notlösung.
  - *B -- beide Quellen knacksen (erledigt, Versorgung):* an 14:E4, Stream
    und A2DP gleichermaßen, Daten im ESP nachweislich sauber
    (Schadenszähler am Ausgang 0). Mit Netzteil statt USB „quasi weg“, am
    COM-Port (CH343) statt am nativen USB ganz weg. Im Zielaufbau läuft
    die Versorgung ohnehin anders; nicht weiter verfolgt. Der PCM5102A ist
    nicht defekt.
  - *C -- Knacksen 2-3,5 s nach dem Stopp von A2DP (weitgehend behoben):*
    Der TinySine treibt SD nach dem Stopp nicht mehr; die offene Leitung
    fing Übersprechen von BCLK/LRCLK ein (100-ms-Spur: Pakete von -33 bis
    -90 dBFS). Der interne Pull-down an I2S DIN (`audio_i2s_start()`) senkt
    das auf meist -84 bis -120 dBFS, einzelne Reste bis -55. Ganz weg nur
    mit externem Pull-down (4,7-10 kOhm SD -> GND); der ADAU1701 hat solche
    Pull-downs von Haus aus. Mit TXB0104 hängt der Pull-down auf der
    3,3-V-Seite; lässt der TinySine SD offen, hängt A3 frei. Kehrt das
    Knacksen nach dem Stopp zurück: 100 kOhm von A3 nach GND (der TXB
    verträgt keine Pull-Widerstände unter etwa 50 kOhm).

  **Drift der Clients, behoben 2026-09-24:** Seit 2026-09-19 schrieb der
  Echtzeit-Task der Clients (`player_task`) alle 5 s vier Log-Zeilen samt
  Heap-, Stationslisten- und CPU-Abfrage. Das blockierte ihn länger als die
  40 ms I2S-Empfangspuffer, Samples gingen verloren, die Ausgabe lief kurz
  leer, und der Plan fiel ~1,5 ms/s zurück (gemessen „I2S clock“ −1500 ppm auf
  B6:88 und BD:FC, harter Resync etwa jede Minute). Das Protokollieren läuft
  jetzt in `sink_stats_task` (Kern 0, Priorität 2); danach auf BD:FC über
  3 min `err` −2…−9 ms, `ppm` 13–28, kein Resync.

- Stufe 7 (Stufe 2 des Server/Client-Plans: Zeit-Sync und Drift, 2026-09-17):
  der Client richtet seine Wiedergabe jetzt auf die Serveruhr aus statt nur
  dem Ringpuffer zu folgen. `snapclient.c` macht den vollständigen
  Vierzeiten-Austausch über `SNAP_MSG_TIME` (t1 lokal gesendet, t2/t3 aus
  `received_*`/`sent_*` der Antwort, t4 lokal empfangen) und veröffentlicht
  aus einem gleitenden Fenster von 12 Messungen die **mit der kleinsten
  RTT** — im Multi-Hop-Mesh hat die RTT-Verteilung einen langen Schwanz, und
  ein verzögertes Paket verfälscht seine eigene Offset-Schätzung um etwa die
  halbe Zusatzverzögerung; Mitteln würde das hineinrechnen statt es zu
  verwerfen. Die Anfragen ersetzen zugleich den in Stufe 6 eingebauten
  reinen Herzschlag. `handle_server_settings()` wertet jetzt `bufferMs` und
  `latency` aus, `handle_wire_chunk()` reicht den Chunk-Zeitstempel weiter.
  `audio_sink.c` führt daraus eine Wiedergabe-Zeitachse: Soll-Zeitpunkt =
  `chunk_ts - offset + bufferMs - latency + delay_trim_ms`, verglichen mit
  `esp_timer` plus `AUDIO_I2S_TX_LATENCY_US` (die DMA-Kette hängt der
  Schreibfunktion um 40 ms hinterher, dafür sind die DMA-Konstanten jetzt in
  `audio_i2s.h` öffentlich). Fehler über 100 ms werden hart korrigiert
  (Überspringen wenn zu spät, Stille halten wenn zu früh), darunter
  kontinuierlich über das Resampling-Verhältnis: PI-Regler, auf +-200 ppm
  begrenzt, mit Slew-Limit von 5 ppm je 20-ms-Frame. Neu dafür
  `audio_resample.c` mit 32.32-Phasenakkumulator (die 16.16-Variante der
  Referenz quantisiert auf ~15 ppm und ist damit gröber als die zu
  korrigierende Drift).

  Zwei Dimensionierungsfehler fielen beim Durchrechnen auf und sind
  mitgefixt: (1) Der Ring war auf exakt `buffer_ms` dimensioniert, obwohl
  das die *Dauerfüllung* ist und nicht die Obergrenze — der Server stempelt
  einen Chunk beim Aufnehmen, der Client spielt ihn `buffer_ms` später, also
  sind permanent `buffer_ms` unterwegs. Er lief damit dauerhaft am Anschlag
  und hätte ankommendes Audio verworfen; Kapazität jetzt doppelt so groß
  wie die Soll-Füllung, die Prebuffer-Schwelle bezieht sich auf letztere.
  (2) Solange kein Zeit-Sync steht, wurde der Regler je Frame komplett
  zurückgesetzt — das verwirft auch den Staging-Rest des Resamplers und
  hätte 50-mal pro Sekunde ein Sample verschluckt; getrennt in vollen Reset
  (nur bei echten Brüchen) und reine Reglerneutralisierung.

  Ebenfalls umgesetzt (Plan-Punkt 13): der Server verzögert seine **eigene**
  lokale Ausgabe um `buffer_ms + delay_trim_ms`. Ohne das spielt sein
  Lautsprecher systematisch `bufferMs` — also per Default drei Sekunden — vor
  jedem Client, weil er einen Frame direkt nach der Aufnahme ausgibt, während
  die Clients denselben Chunk laut Zeitplan erst `bufferMs` später spielen.
  Die Verzögerungsleitung sitzt in `audio_i2s_read_frame()` und damit
  ausschließlich im Server-Pfad; der Client darf nicht ein zweites Mal
  verzögert werden, sein Scheduler platziert die Ausgabe ja bereits. Wichtig
  dabei: verzögert wird nur die Kopie für den Lautsprecher, **nicht** der
  Puffer, den der Opus-Encoder bekommt — sonst ginge der Netzwerk-Stream
  ebenfalls verzögert raus und der Effekt verdoppelte sich beim Client. Der
  Ring ist für den vollen `delay_trim_ms`-Bereich dimensioniert, damit der
  Trim im Betrieb verstellbar bleibt (wirkt über `apply_live_params()`, nur
  in der Server-Rolle). `buffer_ms` löst dafür jetzt einen Reboot aus, weil
  es auf beiden Rollen mehrsekündige Puffer beim Start dimensioniert.
  Konfigurierbarkeit der Server-Verzögerung wurde bewusst weggelassen: ohne
  sie ist das System schlicht unsynchron, ein Schalter dafür hätte keinen
  sinnvollen zweiten Zustand.

  Verifiziert: Build sauber, sowohl mit `CONFIG_SNAPSERVER_ENABLE_MESH_LITE=y`
  als auch `=n`.

- Stufe 8 (zwei Befunde aus dem ersten Zwei-Geräte-Lauf mit Zeit-Sync,
  2026-09-17): (1) Der Regelfehler blieb dauerhaft bei +72…+100 ms stehen,
  während `ppm` an seiner Begrenzung von −200 klebte. Ursache war meine
  eigene Hysterese: Der „zu früh"-Zweig des harten Resyncs hielt Stille nur,
  *bis der Fehler unter die Schwelle fiel*, übergab also systematisch einen
  Restfehler von einer vollen Schwellenbreite (100 ms) an den Feinregler —
  und der braucht bei 200 ppm rund 400 Sekunden für 80 ms. Die
  Einstiegsbedingung war richtig, die Ausstiegsbedingung falsch; gehalten
  wird jetzt, bis der Fehler tatsächlich null ist. Danach gemessen: `err`
  zwischen −3 und −6 ms, `ppm` zwischen 4 und 11, also im Bereich der
  reinen Quarzdrift. (2) Der Client fiel für ~25 s komplett aus dem Netz:
  der Sendepuffer des Servers lief voll (`chunks/s=0`, `skipped` +51/s),
  die Gegenrichtung stand still (`time_msgs` eingefroren), und am Ende warf
  der AP die Station nach sechs unbeantworteten SA-Query-Versuchen raus.
  Verdächtig war ESP-IDFs Default-Powersave für verbundene Stationen
  (`WIFI_PS_MIN_MODEM`, Listen-Interval 3 ⇒ bis zu ~307 ms Funkstille) —
  das passt sowohl zu den vollgelaufenen TCP-Puffern als auch zu den
  verpassten Managementframes und bringt bei netzbetriebenen Lautsprechern
  ohnehin nichts. `esp_wifi_set_ps(WIFI_PS_NONE)` in beiden Rollen; bei mir
  läuft es damit spürbar besser.

  Offen und noch nicht gemessen: Synchronität zweier Clients über längere
  Zeit, Verhalten bei Parent-Wechsel, Wirkung von `delay_trim_ms`, und ob
  Server- und Client-Lautsprecher nach der Delay-Line hörbar zusammenpassen.
  Die PI-Parameter (Kp/Ki, ±200 ppm, 5 ppm Slew je Frame) sind ohne Messung
  konservativ gesetzt; die `err=`/`ppm=`-Werte der `AUDIO_SINK`-Statuszeile
  sind zum Nachjustieren gedacht. Falls die Funkverbindung weiterhin
  aussetzt, ist der nächste Kandidat `esp_mesh_lite_set_wifi_reconnect_interval(2, 3, 5)`
  in `mesh_client.c`: alle 5 s ein voller Scan zwingt das Funkmodul vom
  Kanal und ist eine bekannte Ursache für TCP-Hänger. Der Wert stammt aus
  Stufe 6 und war bewusst aggressiv gewählt, weil das Zielumfeld
  „hochdynamisch" sein soll — schnelles Wiederfinden gegen stabilen Stream
  ist gegeneinander abzuwägen.

- Stufe 9 (Mehr-Client-Betrieb, 2026-09-18). Fünf Clients gleichzeitig
  laufen jetzt mit `skipped=0`; die Ursachenkette dahin steht in den Commits
  `9c00054`…`49bb6c0`. Was daraus offen bleibt:

  **Fusion-Intervall auf 20 s — beobachten.** `esp_mesh_lite_set_fusion_config()`
  in `mesh_client.c` steht auf `fusion_frequency_sec = 20` statt der
  voreingestellten 600. Der Grund war eine Mesh-Insel: fällt der Root weg,
  sehen die übrigen Knoten weiterhin gegenseitig ihre Beacons und melden sich
  aneinander an. Das Ergebnis ist assoziiert, hat eine DHCP-Lease und sieht
  von innen gesund aus, hat aber keinen Weg zum Server — und scannt deshalb
  nie neu. Fusion ist der Mechanismus, der getrennte Meshes wieder
  zusammenführt, und zehn Minuten Wartezeit darauf sind zu lang.
  Der Haken: die Doku sagt „during fusion, the device to be fused will scan
  the primary fusion device". Ob dieser Scan auch dann läuft, wenn gar keine
  Insel existiert, ist nicht nachlesbar — die Bibliothek liegt nur
  vorkompiliert vor. Falls ja, wäre das alle 20 s ein kurzer Ausflug vom
  Kanal, also genau die Störungsart, die uns die Aussetzer beschert hat.
  Im Lauf vom 2026-09-18 war davon nichts zu sehen (65 s durchgehend
  `err=-7…-11 ms`, `ppm 12–25`, serverseitig `skipped=0`). **Wenn wieder
  regelmäßige kleine Einbrüche auftauchen, ist das der erste Verdächtige**;
  Gegenmaßnahme wäre 60 s statt 20 s — immer noch zehnmal schneller als der
  Standard. Dasselbe gilt für das schon weiter oben vermerkte
  `esp_mesh_lite_set_wifi_reconnect_interval(2, 3, 5)`.

  **Doppelte IP nach Server-Neustart — erledigt 2026-09-23.** Der Server
  vergibt bei jedem Start aus der jeweils anderen Hälfte des Netzes
  (`.2–.101` / `.102–.201`, gemerkt im NVS unter `dhcps/half`, siehe
  `provisioning_pin_ap_ip()`). Eine Adresse aus dem vorigen Lauf wird so nie
  neu vergeben; ein Gerät, das sie weiterbenutzt, bekommt bei der nächsten
  Verlängerung ein NAK. Nur wer zwei Neustarts ohne DHCP übersteht, könnte
  noch kollidieren. Achtung beim Lesen der Client-Liste: dieselbe IP bei zwei
  Clients ist meist keine Doppelvergabe, sondern ein Gerät (z. B. ein Handy)
  am AP eines ESP-Clients, das per NAPT mit dessen Adresse ankommt.
  Ursprüngliche Beschreibung: Die
  DHCP-Lease-Tabelle des Servers liegt im RAM und ist nach einem Neustart
  leer. Clients, die durchgelaufen sind, behalten ihre Adresse, während der
  frische DHCP-Server dieselbe an den nächsten Anfragenden vergibt. Zwei
  Stationen, eine Adresse, ein ARP-Eintrag am Root — die SYNs des einen
  laufen ins Leere (auf Gerät gesehen: 48 s Timeouts bei −36 dBm direkt am
  Root, behoben erst durch einen Rejoin mit neuer Adresse). Der
  Unreachable-Watchdog in `snapclient.c` räumt das nach ~20 s auf, die
  Ursache bleibt. Denkbare echte Fixes: feste Adressen je Client statt DHCP,
  oder die Lease beim Verbindungsverlust freigeben. Erst messen, ob es nach
  dem Watchdog überhaupt noch stört.

  **`SNAPSERVER_MAX_CLIENTS = 10` ist gerechnet, nicht getestet.** Nachdem
  die Task-Stacks im PSRAM liegen, kostet ein Client intern nur noch seinen
  lwIP-Socket, rund 6 kB. Bei ~121 kB freiem internem Heap nach dem Start
  sollten zehn Clients rund 60 kB übrig lassen. Gemessen wurde bisher bis
  fünf (`min_ever` ≈ 43–105 kB). Ob der WLAN-Treiber bei zehn
  Unicast-Streams noch etwas anderes reißt, ist offen — die `heap:`-Zeile
  beantwortet es.

  **`frame delta`-Spitzen wachsen mit der Client-Zahl.** Der Mittelwert
  bleibt bei 20000 µs, aber `max` ist von ~22 ms auf 30–38 ms gestiegen. Bei
  40 ms DMA-Reserve ist das noch tragbar, der Abstand ist aber kleiner als
  vorher. Frühwarnzeichen wäre die Rückkehr von
  `AUDIO_I2S: Capture timeline drifted`.

- **Task-Prioritäten für `client_task`/`server_task`/Control-Tasks gesenkt
  und wieder verworfen (2026-09-19).** Ansatz: die kurzen Verschlucker beim
  Client-Beitritt/-Abgang kamen davon, dass `client_task` (Handshake,
  Hello-Parsing per cJSON, Time-Antworten), `server_task` (accept) und die
  Control-Tasks alle auf derselben Priorität wie die Sender-Tasks liefen —
  FreeRTOS teilt bei Gleichstand reihum zu, ein beitretender Client nahm den
  Sendern der laufenden Clients also Slots weg. Umgesetzt:
  `SENDER_TASK_PRIORITY` unverändert bei 5, `CLIENT_TASK_PRIORITY`/
  `SERVER_TASK_PRIORITY` auf 4, `CTRL_SERVER_PRIORITY`/`CTRL_CONN_PRIORITY`
  auf 3.

  **Ergebnis bei mir: deutlich schlechter, nicht besser.** Nicht weiter
  diagnostiziert, Änderung direkt verworfen (nie committet, `git checkout`
  auf `snapserver.c`/`snapcontrol.c`). Vermutung, nicht verifiziert: die
  Time-Antworten laufen über `client_task`, das jetzt gegen Sender *und*
  `server_task` konkurriert statt mit ihnen gleichauf zu liegen — das könnte
  Time-Sync/Handshakes ausgehungert statt nur verzögert haben, was eher zu
  „drastisch schlechter" passt als zu leicht spürbarem Ruckeln.

  Falls das Verschlucker-Problem beim Client-Beitritt nochmal angegangen
  wird: nicht pauschal alles unter die Sender schieben. Eher gezielt nur
  `server_task` (accept) absenken und `client_task` auf Priorität mit den
  Sendern lassen, oder das Hello-Parsing/JSON-Bauen aus `client_task` in
  einen eigenen, niedrig priorisierten Schritt auslagern.

- **Aussetzer beim Client-Abgang: Server-Rückstand statt Verwerfen
  (2026-09-19).** Gemessen statt geraten: Ein Client wird abgeschaltet, und
  für ~3 s bricht der Durchsatz *aller* übrigen Clients gleichzeitig auf
  rund ein Drittel ein (vermutlich hält der AP Sendezeit und die gemeinsamen
  WLAN-Sendepuffer mit Wiederholungen an die verschwundene Station fest —
  nicht belegt). Der Server konnte pro Client aber nur ~0,4 s vorhalten
  (8 Chunks Queue + TCP-Sendepuffer) und warf den Rest weg: 54–113
  `skipped` pro Client, im Client-Log `shift`/`resync` — hörbare Löcher,
  obwohl der Client-Puffer (3 s) den Einbruch hätte überbrücken können.

  Umgesetzt in `snapserver.c`: Queue 120, Chunk-Pool 128 (Speicher im
  PSRAM), der Sender wiederholt einen abgelehnten Chunk statt ihn zu
  verwerfen, und verworfen wird nach Alter (`bufferMs − 600 ms`, max.
  2,4 s). **Ergebnis auf Gerät:** Abgang eines Clients bei vier laufenden —
  `skipped=0` bei allen übrigen, im Client-Log sichtbares Aufholen
  (`fed` erst unter, dann über 480000 B pro 5 s), `shift`/`resync`/
  `underrun` unverändert, `min_ever` 68 KB statt 30 KB.

  Offen: Der Einbruch selbst bleibt (er wird nur überbrückt); ein Stau
  länger als ~2,4 s verliert weiterhin Audio. Einmal gesehen, nicht
  reproduziert: ein Level-2-Client, dessen Verbindung beim Abgang eines
  *anderen* Clients per RST (`Connection reset by peer`, vermutlich aus der
  NAPT seines Parents) abriss — der Client selbst merkte es erst nach 6 s
  am Stall-Watchdog. Bei Wiederauftreten das Log des Parents mitschneiden.

- **Sprachdurchsagen (`test/voice`): Stand und Offenes (2026-09-19).**
  Seit 2026-09-19 committet (773851a ff.) und in `main`. Stand damals auf
  Gerät: Server geflasht mit getrenntem Relay-/Speaker-Task, Clients auf
  dem Stand davor (Heap- und CPU-Zeile schon drin), App mit 16 kHz
  installiert. Hört sich viel besser an.

  Gemessen bei der letzten Durchsage:
  - Clients: `voice_underrun` 0–2,4 % statt 15 %, Kern 1 zu 65 % frei.
  - Server: Kern 1 fast voll. `opus_audio` 76–78 % (ohne Durchsage 55 %),
    `voice_speaker` 16–18 %, `IDLE1` 5 %. `Server decode: avg=13 ms
    max=101 ms` (Uhrzeit, nicht CPU), 8 von 900 Paketen nicht gespielt.
  - App: Verstärkung dauerhaft am Anschlag (24 dB), Mikrofon −33…−46 dBFS,
    Ausgang −26…−39 dBFS RMS, also eher leise.

  **Tests (für den nächsten Termin geplant):**
  1. Lautstärke und Hall der Durchsage beurteilen.
  2. Mikrofonquellen „Standard-Mikrofon“ und „Spracherkennung“ gegen
     „Telefonat“ vergleichen. Eine lautere Quelle braucht weniger
     Verstärkung und bringt weniger Hall. Danach den Regler
     „Max. Verstärkung“ nach Gehör einstellen und den Default in
     `SettingsStore.kt` anpassen.
  3. Klingt der Server-Lautsprecher schlechter als die Clients? Wenn ja,
     siehe unten „Server-Kern 1“.
  4. Clients mit dem aktuellen Stand flashen (Code dort unverändert, nur
     damit alle gleich sind) und eine Kette erzwingen (mehrere Knoten hinter
     einem Relay). Dabei `heap … children=` und `cpu` des Relays
     mitschneiden. Das beantwortet, ob die Relay-Hänger von heute am
     internen RAM liegen.
  5. Zwei Durchsagen direkt nacheinander, App-Kill mitten in der Durchsage,
     WLAN-Verlust am Handy: Wächter und Unmute prüfen. Das ging schon
     einmal, aber vor dem Umbau auf zwei Tasks.

  **Offen, Durchsage:**
  - **Server-Kern 1:** Während einer Durchsage die Komplexität des
    Musik-Encoders senken (erledigt: `VOICE_MUSIC_COMPLEXITY` 0 in
    `voice_announce.c`). Ungeklärt bleibt: Warum steigt
    der Encoder während der Durchsage von 55 % auf 78 %? Vermutung:
    Encoder und Decoder stören sich im gemeinsamen PSRAM-Cache. Nicht
    gemessen.
  - **Encoder allgemein:** 55 % eines Kerns für Mono mit 96 kbit/s bei
    Komplexität 5 ist viel. Laut micro-opus-Benchmark wäre eher ~30 % zu
    erwarten. Kandidaten: Floating-Point-Build
    (`CONFIG_OPUS_FLOATING_POINT=y`, laut Doku beim Encodieren langsamer
    als Fixed-Point), Pseudostack im PSRAM.
  - **Last auf Kern 0 während der Durchsage:** `tiT` 29 % und `wifi` 25 %
    statt 8 % und 6 %. Drei UDP-Ströme mit 25 kbit/s erklären das nicht.
    Ursache unbekannt.
  - **`voice_dropped` bei den Clients:** Pakete kommen in Schüben, der
    60-ms-Puffer (`VOICE_MAILBOX_CAPACITY_SAMPLES`) läuft kurz über.
    Größer machen kostet Latenz. Erst nach den Tests entscheiden.
  - **Root-Bindung des Handys:** Serverseitige Erkennung, ob das Handy
    direkt am Root hängt, plus gezieltes Verbinden per
    `WifiNetworkSpecifier`. Siehe den Eintrag zur Standort-Berechtigung
    unten, dort steht der Weg ohne Berechtigung.
  - **`tools/voice_test.py`** sendete rohes PCM und passte nicht mehr zur
    Opus-Firmware. Entfernt 2026-10-07.
  - **`docs/code-review-voice.md`:** Status von M3 (Vorpuffer) nachtragen,
    ist umgesetzt. Den Umbau auf zwei Server-Tasks ergänzen.

  **Offen, Robustheit (gehört eher auf `test/ServerClient`):**
  - **Relay hängt sich auf**, wenn mehrere Kinder an ihm hängen (heute
    zweimal, verschiedene Geräte: Reason-15-Abbrüche bei den Kindern bzw.
    `STA not responded to 6 SA Query attempts`). Das schlauchförmige Netz
    macht solche Ketten zum Normalfall, sie dürfen nicht zum Totalausfall
    führen. Erst messen (Test 4), dann als Kandidat
    `CONFIG_SPIRAM_TRY_ALLOCATE_WIFI_LWIP=y` (WLAN- und lwIP-Puffer im
    PSRAM) versuchen. Gesetzt seit 2026-09-23 (60a13e3); ob die Hänger
    damit weg sind, ist nicht festgehalten.
  - **Server erstickt an einem hängenden Zweig:** interner Heap bis auf
    172 B bzw. 128 B (`min_ever`), `send stalled` bei allen. Er muss früher
    erkennen, dass ein Client nichts abnimmt, und aufhören, dessen Pakete in
    die WLAN-Puffer zu schieben, statt 20 s zu warten. Seit 2026-10-01
    (44fc601) schließt der Server einen Client, wenn 3 s lang mehr
    verworfen als zugestellt wird; ob das diesen Fall abdeckt, ist nicht
    festgehalten.
  - **Musik-Aussetzer bei 14E4 trotz −11 dBm** direkt am Server:
    `chunks/s=0` für mehrere Sekunden, `skipped=315`, die anderen Clients
    in derselben Zeit sauber. Einmal gesehen, Ursache unbekannt.

  **Diagnose-Code, später aufräumen oder behalten:**
  - `main/cpu_stats.c` und die FreeRTOS-Laufzeitstatistik in
    `sdkconfig.defaults` (ein Timer-Zugriff pro Taskwechsel).
  - `heap … children=` in der Client-Statuszeile, Decodierzeit-Messung in
    `voice_announce.c`.
  - Die Puffer der CPU-Anzeige liegen statisch: Auf dem 3-KB-Stack von
    `snapstats` hatten sie einen Stack-Overflow ausgelöst.

  **Hinweise für die Tests:**
  - `idf.py monitor` setzt den ESP beim Verbinden zurück. Zum
    Mitschneiden ohne Neustart `--no-reset` verwenden. Unter Linux löst
    schon das Öffnen des Ports über pyserial einen Reset aus, obwohl DTR/RTS
    vorher abgeschaltet sind (beobachtet).
  - Die iot_bridge-Komponente meldet bei jedem Neukonfigurieren
    fehlgeschlagene lwIP-Patches. Die Meldung ist nicht neu. Der NAPT-Patch
    ist eingespielt, die anderen drei greifen in ESP-IDF 5.4.3 nicht.
    Vermutung: dort schon enthalten. Nicht geprüft.

- **Wiedergabe-Synchronität Server gegen Clients (2026-09-20).** Der Server
  lag hörbar hinter seinen Clients. Drei Ursachen, zwei davon hergeleitet,
  eine nach Gehör:
  1. **40 ms TX-Warteschlange.** Die Clients planen ihre Wiedergabe um
     `AUDIO_I2S_TX_LATENCY_US` früher, die Verzögerungsleitung des Servers
     tat das nicht. Behoben in `audio_i2s_set_output_delay()`.
  2. **20 ms Framelänge.** Ein Chunk wird auf den *Anfang* seines Frames
     gestempelt, erreicht die Verzögerungsleitung aber erst, wenn der Frame
     vollständig aufgenommen ist. Ebenfalls dort abgezogen.
  3. **Kein weiterer Zuschlag.** `SERVER_LEAD_MS` steht auf 20 ms, also
     genau dem hergeleiteten Wert aus Punkt 2. Nach Gehör wurden 30, 40 und
     50 ms probiert, alle klangen schlechter.

     **Weiteres Einstellen nach Gehör ist sinnlos**, solange die Clients
     ihre Wiedergabe selbst um mehr verschieben, als diese Schritte groß
     sind: Der Regelfehler schwankt um zehn und mehr Millisekunden, und ein
     harter Resync verschiebt ihn in einem Sprung. Für eine echte Aussage
     bräuchte es eine Messung, wann ein bekanntes Signal tatsächlich jeden
     Lautsprecher verlässt. Kandidaten für einen echten Restversatz sind
     die Vorausschau des Opus-Encoders (~6,5 ms) und der Frameaufbau im
     Client. **Das ist die erste Stelle, an der man drehen sollte**, falls
     die Lautsprecher je neu auszurichten sind. `delay_trim_ms` steht dafür
     nicht mehr zur Verfügung, es ist im Server ausgebaut.

  **Stand 2026-10-02:** Zeitabgleich und Sprünge der Clients überarbeitet,
  siehe `docs/releases/v0.5.1.md` bis `v0.5.3.md`. Laut v0.5.2 liegen die
  Clients untereinander unter 2–3 ms (vorher 5–8 ms); seit v0.5.3 wirken
  Latenz und Delay je Client sofort und auf das Sample genau. Die Messung
  Server ↔ Clients am Lautsprecher fehlt weiterhin.

  **Drift-Regelung:** `AUDIO_RESAMPLE_MAX_PPM` und
  `CONTROL_INTEGRAL_CLAMP_PPM` standen auf 200 bzw. 100 ppm. Beobachtet
  wurde, wie die Regelung am Anschlag klebte, während der Fehler auf über
  70 ms wuchs und dann per hartem Resync zurücksprang. Beide stehen jetzt
  auf 500 ppm. Im eingeschwungenen Zustand braucht die Regelung nur
  einstellige bis niedrige zweistellige ppm, die Grenze ist also Reserve
  zum Aufholen, keine Dauerkorrektur.

- **`audio_i2s_clock_ppm()` ist unzuverlässig (2026-09-20).** Die Funktion
  soll den I2S-Takt gegen `esp_timer` messen. Ihre Werte schwanken zwischen
  Läufen desselben Geräts um mehrere hundert ppm (Server einmal −600, dann
  −295), was ein Quarz nicht tut. Ursache vermutlich der Ankerzeitpunkt vor
  dem eingeschwungenen Zustand. Auf einer früheren Fassung, die im
  Aufnahmepfad statt im Ausgabepfad zählte, waren die Werte noch stärker
  verfälscht, weil ein Client nicht in jedem Durchlauf liest.

  **Konsequenz: Die daraus abgeleitete Behauptung, der Server laufe ~870 ppm
  neben seinen Clients, ist nicht belegt.** Entweder die Messung reparieren
  (Anker erst nach einigen Sekunden setzen, über ein gleitendes Fenster
  statt seit dem Start rechnen) oder sie wieder entfernen.

- **Akustische Artefakte im Eingangssignal (2026-09-20; behoben 2026-09-25,
  siehe Fehler A: TinySine mit 1,8 V I2S-Pegel, TXB0104).** Traten
  gleichzeitig auf Server und allen Clients auf, nur bei laufendem Stream,
  und verschwanden nach einigen Minuten von selbst. Der Server-Lautsprecher
  hängt nicht am Netzwerk, sein Signal kommt direkt vom I2S-Eingang: Mesh,
  Snapcast, Ringpuffer, Drift-Regelung und Durchsage-Pfad scheiden damit
  aus, die Störung steckt bereits im aufgenommenen Signal. Zähler zeigten
  nichts (`underrun=0`, `skipped=0`, keine Clipping-Spitzen, Peaks bei
  13000–18000 von 32767). Zum Eingrenzen fehlt eine feinere Messung des
  Eingangspegels, etwa die Zahl der Frames je Sekunde unter einer Schwelle.
  Nachtrag 2026-09-25: Das Bild -- nur der I2S-Eingang betroffen, nach
  Minuten von selbst weg -- entspricht genau den wandernden Störphasen von
  Fehler A. Mit Pegelwandler nicht mehr aufgetreten.

- **Durchsage-App: Standort-Berechtigung (entfällt, geprüft 2026-10-01).**
  Geplant war, die BSSID per `ACCESS_FINE_LOCATION` zu lesen, um zu
  erkennen, ob das Handy direkt am Root hängt, und die Berechtigung danach
  wieder zu entfernen. Eingebaut wurde sie nie: Das Manifest hat keine
  Standort-Berechtigung, die App liest keine BSSID. Falls die Erkennung
  doch kommt, dann ohne Berechtigung über den Server (Owner-IP aus
  `voice_announce_rpc_start()` ist Level-1-Station und gehört keinem
  ESP-Client; Ergebnis in der `Voice.Start`-Antwort).

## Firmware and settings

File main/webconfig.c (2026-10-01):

/**
 * @file webconfig.c
 * @brief Config web UI: HTTP server, JSON API, embedded page, mDNS.
 */
#include "webconfig.h"

#include <stdbool.h>
#include <stdlib.h>
#include <string.h>

#include "audio_i2s.h"
#include "audio_opus.h"
#include "audio_sink.h"
#include "cJSON.h"
#include "client_store.h"
#include "device_config.h"
#include "esp_app_desc.h"
#include "esp_heap_caps.h"
#include "esp_http_server.h"
#include "esp_log.h"
#include "esp_mac.h"
#include "esp_system.h"
#include "esp_timer.h"
#include "esp_wifi.h"
#include "mdns.h"
#include "pinmap.h"
#include "pots.h"
#include "provisioning.h"
#include "snapclient.h"
#include "snapserver.h"
#include "sdkconfig.h"
#if CONFIG_SNAPSERVER_ENABLE_MESH_LITE
#include "esp_mesh_lite.h"
#endif

static const char *TAG = "WEBCONFIG";

/* The full form with a 64-character password and the knob fields comes to
 * roughly 800 bytes; 1536 leaves room without growing the 8 KB handler
 * stack meaningfully. */
#define WEBCONFIG_MAX_BODY 1536
#define WEBCONFIG_REBOOT_DELAY_US (1500LL * 1000LL)

/* gzip-compressed at build time, see main/CMakeLists.txt. */
extern const uint8_t webconfig_page_gz_start[] asm("_binary_webconfig_page_html_gz_start");
extern const uint8_t webconfig_page_gz_end[] asm("_binary_webconfig_page_html_gz_end");

static httpd_handle_t s_server;
static esp_timer_handle_t s_reboot_timer;

/* ------------------------------------------------------------------ */
/* Deferred reboot                                                    */
/* ------------------------------------------------------------------ */

static void reboot_timer_cb(void *arg)
{
    (void)arg;
    esp_restart();
}

static void schedule_reboot(void)
{
    /*
     * A reboot is coming either way, so any pending provisioning-AP timeout
     * would just be redundant noise in the log if it fired first -- cancel
     * it defensively rather than let both race.
     */
    provisioning_cancel_ap_timeout();

    /*
     * s_reboot_timer is created once in webconfig_start(), where a failure
     * can be logged properly. If that creation failed, the handle stays
     * NULL forever -- falling back to an immediate esp_restart() here means
     * the in-flight HTTP response gets cut off, but that beats the UI
     * claiming "rebooting..." while nothing happens.
     */
    if (s_reboot_timer == NULL) {
        ESP_LOGW(TAG, "No reboot timer available, restarting immediately");
        esp_restart();
        return;
    }
    esp_timer_start_once(s_reboot_timer, WEBCONFIG_REBOOT_DELAY_US);
}

/* ------------------------------------------------------------------ */
/* JSON helpers                                                       */
/* ------------------------------------------------------------------ */

static void parse_bool_field(const cJSON *root, const char *key, bool *out)
{
    const cJSON *item = cJSON_GetObjectItemCaseSensitive(root, key);
    if (cJSON_IsBool(item)) {
        *out = cJSON_IsTrue(item);
    }
}

static bool parse_number_field(const cJSON *root, const char *key, double *out)
{
    const cJSON *item = cJSON_GetObjectItemCaseSensitive(root, key);
    if (cJSON_IsNumber(item)) {
        *out = item->valuedouble;
        return true;
    }
    return false;
}

/* Empty string means "leave unchanged" -- used for mesh_ssid, since an SSID
 * can never usefully be blank, so an accidental empty submit should not
 * wipe a saved one. mesh_password uses parse_password_field() instead: an
 * empty password is a valid, deliberate choice (an open network), so it
 * must overwrite like any other value -- see config_is_valid() in
 * device_config.c, which already accepts a zero-length password. */
static void parse_string_field(const cJSON *root, const char *key, char *out, size_t out_len)
{
    const cJSON *item = cJSON_GetObjectItemCaseSensitive(root, key);
    if (cJSON_IsString(item) && item->valuestring[0] != '\0') {
        strlcpy(out, item->valuestring, out_len);
    }
}

static void parse_password_field(const cJSON *root, const char *key, char *out, size_t out_len)
{
    const cJSON *item = cJSON_GetObjectItemCaseSensitive(root, key);
    if (cJSON_IsString(item)) {
        strlcpy(out, item->valuestring, out_len);
    }
}

/*
 * esp_http_server runs handlers on a single task by default, so a client
 * that stalls mid-body would otherwise wedge every other request behind an
 * unbounded retry loop. Give up after a handful of consecutive timeouts
 * instead of retrying forever.
 */
#define WEBCONFIG_MAX_RECV_TIMEOUTS 5
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

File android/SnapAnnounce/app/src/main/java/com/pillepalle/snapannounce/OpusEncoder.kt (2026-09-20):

package com.pillepalle.snapannounce

import android.media.MediaCodec
import android.media.MediaCodecInfo
import android.media.MediaFormat
import java.nio.ByteOrder

/**
 * Android's built-in Opus encoder (MediaCodec, Android 10+), mono, at the
 * caller's sample rate, wrapped for a synchronous capture loop.
 *
 * Opus rather than raw PCM: at 768 kbit/s per level-1 client, raw PCM
 * needed about nine times the music's airtime and congested the mesh --
 * see voice_announce.c. The ESP32s decode with the same libopus they use
 * for the music.
 *
 * Every output buffer from MediaCodec's Opus encoder is exactly one raw
 * Opus packet (no container), which is what goes on the wire. The first
 * few are codec-specific data (OpusHead, pre-skip, seek pre-roll), flagged
 * BUFFER_FLAG_CODEC_CONFIG; a decoder that is fed packets directly doesn't
 * need them, so they are skipped.
 *
 * Never blocks the capture thread for long: if the encoder has no free
 * input buffer within ENCODER_WAIT_US, that 10 ms is dropped rather than
 * waited for -- the same "drop, don't wait" rule as the rest of the path.
 */
class OpusEncoder(private val sampleRate: Int, bitrate: Int) {

    private val codec: MediaCodec = MediaCodec.createEncoderByType(MediaFormat.MIMETYPE_AUDIO_OPUS)
    private val info = MediaCodec.BufferInfo()
    private val out = ByteArray(1275)
    private var samplesIn = 0L
    private var samplesOut = 0L

    /**
     * Audio handed in but not yet handed back, in milliseconds -- the delay
     * the encoder itself adds. Part of it is Opus' own frame and lookahead,
     * the rest is however much MediaCodec keeps in flight, which is not
     * documented and differs between devices. Measured because it sits in
     * the announcement's end-to-end latency, which is the whole point of
     * this path.
     */
    val backlogMs: Double
        get() = (samplesIn - samplesOut) * 1000.0 / sampleRate

    init {
        val format = MediaFormat.createAudioFormat(MediaFormat.MIMETYPE_AUDIO_OPUS, sampleRate, 1).apply {
            setInteger(MediaFormat.KEY_BIT_RATE, bitrate)
            setInteger(MediaFormat.KEY_BITRATE_MODE, MediaCodecInfo.EncoderCapabilities.BITRATE_MODE_VBR)
            setInteger(MediaFormat.KEY_MAX_INPUT_SIZE, 4 * 480 * 2)
        }
        try {
            codec.configure(format, null, null, MediaCodec.CONFIGURE_FLAG_ENCODE)
            codec.start()
        } catch (e: Exception) {
            codec.release()
            throw e
        }
    }

    /**
     * Queues [pcm] (native-endian 16-bit mono) and hands every finished
     * packet to [onPacket] as (buffer, length). The buffer is reused.
     */
    fun encode(pcm: ShortArray, onPacket: (ByteArray, Int) -> Unit) {
        val inIndex = codec.dequeueInputBuffer(ENCODER_WAIT_US)
        if (inIndex >= 0) {
            val input = codec.getInputBuffer(inIndex)
            if (input != null) {
                input.clear()
                input.order(ByteOrder.nativeOrder()).asShortBuffer().put(pcm)
                val ptsUs = samplesIn * 1_000_000L / sampleRate
                codec.queueInputBuffer(inIndex, 0, pcm.size * 2, ptsUs, 0)
                samplesIn += pcm.size
            }
        }

        while (true) {
            val outIndex = codec.dequeueOutputBuffer(info, 0)
            if (outIndex == MediaCodec.INFO_OUTPUT_FORMAT_CHANGED) continue
            if (outIndex < 0) break

            val isConfig = (info.flags and MediaCodec.BUFFER_FLAG_CODEC_CONFIG) != 0
            if (!isConfig) {
                /* One packet is one Opus frame; 20 ms is what this encoder
                 * produces at every rate we use. */
                samplesOut += sampleRate / 50
            }
            if (!isConfig && info.size in 1..out.size) {
                val output = codec.getOutputBuffer(outIndex)
                if (output != null) {
                    output.position(info.offset)
                    output.limit(info.offset + info.size)
                    output.get(out, 0, info.size)
                    onPacket(out, info.size)
                }
            }
            codec.releaseOutputBuffer(outIndex, false)
        }
    }

    fun release() {
        try {
            codec.stop()
        } catch (_: IllegalStateException) {
        }
        codec.release()
    }

    private companion object {
        const val ENCODER_WAIT_US = 5_000L
    }
}

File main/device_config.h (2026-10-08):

/**
 * @file device_config.h
 * @brief NVS-backed runtime configuration (mesh, DSP, Opus).
 *
 * Every field here used to be a Kconfig compile-time constant. The Kconfig
 * values now only seed the defaults used on first boot, after a factory
 * reset, or when a stored blob fails its version check; from then on the
 * values in NVS are authoritative and are edited via the web config page
 * (see webconfig.c).
 */
#pragma once

#include <stdbool.h>
#include <stdint.h>
#include "esp_err.h"

#ifdef __cplusplus
extern "C" {
#endif

#define DEVICE_CONFIG_VERSION 2

/* device_config_t.role. Applying a change requires a reboot. */
#define DEVICE_ROLE_SERVER 0U
#define DEVICE_ROLE_CLIENT 1U

/*
 * device_config_t.source_mode (client role only). Applies live, no reboot.
 * AUTO gives the local I2S input priority whenever a signal is present,
 * falling back to the network stream otherwise -- the same rule the
 * reference ESP32_Mesh_Snapclient project used for A2DP vs. Snapcast.
 */
#define SOURCE_MODE_AUTO         0U
#define SOURCE_MODE_NETWORK_ONLY 1U
#define SOURCE_MODE_LOCAL_ONLY   2U

/* Range of delay_trim_ms. Also bounds how much headroom the server's local
 * output delay line has to reserve so the trim stays adjustable at runtime. */
#define DEVICE_CONFIG_DELAY_TRIM_MAX_MS 2000

/* Range of buffer_ms. Clients size their ring for the maximum. */
#define DEVICE_CONFIG_BUFFER_MIN_MS 200U
#define DEVICE_CONFIG_BUFFER_MAX_MS 10000U

typedef struct {
    uint32_t version;

    /* Mesh / Wi-Fi. Applying a change requires a reboot. */
    bool     mesh_enable;
    char     mesh_ssid[33];
    char     mesh_password[65];
    uint8_t  mesh_channel;
    uint8_t  mesh_max_level;

    /* DSP / crossover. Applies live, no reboot. */
    bool     dsp_bypass;
    uint16_t crossover_hz;
    float    sub_gain_db;
    float    wideband_gain_db;
    uint8_t  sub_channel;
    uint8_t  wideband_channel;

    /* Opus. Applies live, no reboot. */
    uint32_t opus_bitrate;
    uint8_t  opus_complexity;

    /* Provisioning bookkeeping, not user-editable via the config page. */
    uint8_t  boot_fail_count;

    /* Server/client role. Applying a change requires a reboot. */
    uint8_t  role;

    /*
     * Server role: the end-to-end latency, announced to every client as
     * the Snapcast bufferMs (see snapserver.c) and the delay of the
     * server's own speaker. Needs a reboot there. A client plays by the
     * server's value and ignores its own.
     */
    uint16_t buffer_ms;
    int16_t  delay_trim_ms;
    uint8_t  source_mode;
    int8_t   local_input_threshold_db;
    /* Unused since 2026-09-29 (the server is always the mesh root); kept
     * so the blob layout stays the same. */
    char     server_host[32];

    /*
     * Subsonic high-pass on the sub branch in Hz, 0 = off (15-60, below
     * crossover_hz). Applies live. Taken from the reserved bytes, which
     * older blobs hold as 0, so they load unchanged with the filter off.
     */
    uint8_t  sub_hpf_hz;

    /* 1: sub branch polarity inverted (180 degrees). Applies live; from
     * the reserved bytes as well, older blobs load it as 0. */
    uint8_t  sub_invert;

    /*
     * Compressor on both output branches, before the knob. Applies live.
     * Ratio in tenths (30 = 3:1). A blob from before these fields has
     * ratio 0 and gets the defaults below on load, switched off.
     */
    uint8_t  comp_enable;
    int8_t   comp_threshold_db;   /* -40..0 dBFS */
    uint8_t  comp_ratio_x10;      /* 10..100 */
    uint8_t  comp_makeup_db;      /* 0..24 */

    uint8_t  reserved[10];
} device_config_t;

/*
 * Potentiometer inputs (see pots.h). Kept out of device_config_t on
 * purpose: that struct is stored as one versioned blob, and a stored blob
 * whose version does not match is replaced by defaults -- adding fields
 * there would have wiped every device's configuration on update. This one
 * lives under its own NVS key and falls back to defaults field by field.
 *
 * A gpio of 0 means "no knob". Pin changes need a reboot, the delay range
 * and the direction apply live.
 *
 * The *_reversed flags came later. A blob stored before them is
 * DEVICE_POTS_V1_SIZE bytes long and loads with both flags 0.
 */
typedef struct {
    uint8_t  volume_gpio;
    uint8_t  delay_gpio;
    uint16_t delay_range_ms;
    uint8_t  volume_reversed; /* 1: full turn clockwise = silence */
    uint8_t  delay_reversed;
    uint8_t  reserved[2];
} device_pots_t;

#define DEVICE_POTS_V1_SIZE 4U

/* Upper limit for sub_gain_db and wideband_gain_db. */
#define DEVICE_CONFIG_GAIN_MAX_DB 18.0f

#define DEVICE_CONFIG_COMP_DEFAULT_THRESHOLD_DB (-20)
#define DEVICE_CONFIG_COMP_DEFAULT_RATIO_X10    30U
#define DEVICE_CONFIG_COMP_DEFAULT_MAKEUP_DB    6U
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

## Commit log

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2026-09-16 fix: prevent client-slot leak from indefinitely blocked recv()
    client_task() blocked forever in recv() if a Snapcast client vanished
    without a clean TCP FIN/RST (Wi-Fi dropout, sleep, roaming), leaking
    its slot until reboot. Add SO_RCVTIMEO as a backstop and enable real
    TCP keepalive via setsockopt, since CONFIG_LWIP_TCP_KEEPALIVE is not
    an actual ESP-IDF lwip Kconfig symbol and had no effect.
    [snapserver.c]
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2026-09-16 fix: synchronize wall-clock offset access and drop dead root-only config
    s_wall_offset_us is a 64-bit value written from handle_time() and read
    from now_us() and the audio task on other tasks; on this 32-bit target
    that was an unsynchronized, potentially torn access. Guard all reads
    and writes with the existing s_clients_lock, and close a related race
    where two clients could both trigger clock adoption concurrently by
    checking-and-setting s_clock_synced under the same lock.
    Also remove SNAPSERVER_MESH_ROOT_ONLY from Kconfig: it was never read
    anywhere in mesh_root.c, which hardcodes root-only behavior regardless
    of the option's value.
    [snapserver.c]
2026-09-16 fix: synchronize client->peer access during slot claim and teardown
    client->peer was written after leaving the slot-claim critical section
    and read again in close_client() after leaving its own critical
    section. If a new connection claimed the same slot in that window, the
    old session's summary log line could show a partially overwritten IP.
    Move the write inside the claim loop and snapshot peer under the lock
    in close_client() before logging.
    [snapserver.c]
2026-09-17 fix: stop one slow client from stalling audio capture for everyone
    audio_task read/encoded I2S audio and then sent the wire chunk to
    every ready client synchronously in a single loop, with a 2s
    SO_SNDTIMEO blocking send per client. A client with a full TCP send
    buffer (weak mesh link, stalled receiver) stalled that shared task for
    up to seconds, starving I2S capture for all other clients too --
    confirmed live via cascading "Capture timeline drifted" warnings
    climbing to 2.6s right before the slow client's send failed.
    Probe each client's socket with a zero-timeout select() before
    sending; skip the frame for that client (tracked via a new
    chunks_skipped counter) instead of blocking the whole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
    [snapserver.c]
2026-09-17 feat: add web config UI with NVS-backed settings and provisioning AP
    Every device setting used to be a Kconfig compile-time constant, so
    changing the mesh credentials, the crossover or the Opus parameters
    meant a rebuild and a reflash -- and a wrong Wi-Fi setting left no way
    to reach the device at all.
    Settings now live in NVS and are edited over HTTP on port 80. Mesh
    changes (SSID, password, channel, hop depth, enable) apply on the next
    boot, which the save triggers itself; DSP and Opus values apply live,
    without interrupting the stream. The Kconfig options stay as the
    first-boot and factory-reset defaults.
    To keep the device reachable when its stored config cannot work, it
    falls back to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
    [audio_i2s.c, audio_i2s.h, audio_opus.c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]
2026-09-17 fix: address 12 review findings in the provisioning/config feature
    A high-effort review of the config UI + provisioning AP branch turned
    up a real password leak, a way to wedge the single-threaded config
    server permanently, a build break with mesh-lite compiled out, and
    several races between the HTTP task, the provisioning grace-window
    timer, and the audio task. All twelve are fixed here:
    Security/correctness:
    - Reject mesh passwords of 1-7 characters at save time (mesh_root.c
    silently falls back to an open AP below 8 chars, but the config API
    still believed and echoed it as protected).
    - Cap consecutive recv() timeouts in the config server's body reader
    instead of retrying forever, w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
    [audio_i2s.c, device_config.c, device_config.h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]
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2026-09-17 feat: add client role (mesh relay, Snapcast playback, local I2S input)
    Stage 1 of the server/client unification: the same firmware can now boot
    as either a server (mesh root, unchanged) or a client (mesh non-root
    relay), selectable via the web config page and NVS-backed like every
    other setting. The role is stored in device_config_t.role and applied on
    reboot, mirroring the existing pattern for mesh settings changes.
    New client-role code, ported from the ESP32_Mesh_Snapclient reference
    project but without A2DP/Bluetooth (the ESP32-S3 has no Bluetooth
    Classic) and with the local I2S input as the alternate source instead:
    - mesh_client.c: joins the mesh as a non-root relay (never a leaf, so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
    [audio_i2s.c, audio_i2s.h, audio_sink.c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]
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2026-09-17 fix: repair mesh client connectivity, uniqueness and playback stability
    Four bugs found during the first real two-device test on this branch:
    esp_mesh_lite_get_root_ip() returns the root IP byte-reversed (fixed with
    a bswap32 in mesh_client.c); every client advertised a unique MAC-suffixed
    SSID even though Mesh-Lite matches parents via a vendor IE, not the SSID
    text, so all roles now share one SSID; every device advertised the same
    mDNS hostname "snapserver.local", causing DNS/mDNS caches to point at the
    wrong device (now unique per role+MAC, also surfaced in the web config
    page title/heading); and the server's 30s no-traffic client timeout was
    tripping on our own snapclient, which never sen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
    [audio_i2s.h, audio_sink.c, webconfig.c]
2026-09-17 feat: synchronise client playback to the server clock
    Clients now place audio on a real timeline instead of just following the
    ring buffer. snapclient.c runs the full four-timestamp exchange over
    SNAP_MSG_TIME and publishes the offset of the least-delayed measurement in
    a sliding window -- in a multi-hop mesh a delayed packet biases its own
    estimate by about half the excess delay, so averaging would fold that in
    rather than reject it. ServerSettings (bufferMs, latency) and the chunk
    timestamps feed audio_sink.c, which schedules each sample for
    chunk_ts - offset + bufferMs - latency + delay_trim_ms, corrects errors
    above 100 ms in one step and everything below that through the resampling
    rati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
    [audio_i2s.c, audio_i2s.h, audio_sink.c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]
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2026-09-18 feat: decouple the send path from audio capture and survive send stalls
    With four clients the capture loop could no longer hold its 20 ms budget:
    audio_task sent every chunk to every client inline, so the cadence depended
    on how fast the slowest socket drained. Chunks are now published into a
    fixed pool and handed to one sender task per client through a bounded
    queue. audio_task's work is a memcpy plus one queue post per client, and a
    client that falls behind loses its own oldest pending chunk instead of
    stalling the capture.
    Raises MAX_CLIENTS to 10, which needed larger stacks in snapcontrol.c --
    three snapserver_client_info_t[10] stack arrays overflowed the old ones.
    Moves all periodic l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
    [snapserver.c]
2026-09-18 feat: hold client playback steady across volume, drift and timeline shifts
    Three fixes to the client's playback scheduler, all found by running two
    speakers side by side.
    A stream discontinuity no longer flushes the ring. The server re-anchors
    its capture timeline whenever the counted position drifts too far from the
    hardware timer, which shifts every following chunk timestamp at once. The
    client read that as a broken stream, discarded a full buffer of good audio
    and then re-prebuffered it -- an audible gap on every re-anchor. It now
    follows the shift and keeps what it has.
    The hard-resync hold released at the threshold rather than at zero, so it
    stopped correcting the moment the error fel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
    [audio_sink.c]
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2026-09-18 fix: stop the control server hogging internal DRAM, and report the heap
    Three clients was enough to stop the server transmitting to any of them.
    All three went to chunks/s=0 within the same second -- including a phone
    running stock Snapcast, so not a client bug -- and stayed there for ten
    seconds while the capture loop held 20000 us to the microsecond. The CPU
    was idle; only the radio had stopped. Shortly after, the server logged
    "Could not create client task", which is an outright internal-heap
    exhaustion and makes the mechanism hard to argue with: the Wi-Fi driver
    takes its TX buffers from the same DRAM our task stacks came out of.
    The control server was the worst offender per connection.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
    [snapserver.c]
2026-09-18 fix: shrink the per-connection TCP buffers that were starving the Wi-Fi driver
    The heap reporting added in the previous commit answered the question in one
    run. Internal DRAM, with clients joining one after another:
    t= 6.4 s free=92232 largest=31744 min_ever=84056
    t=16.5 s free=81052 largest=31744 min_ever=56020
    t=21.6 s free=64228 largest=21504 min_ever=10140
    t=26.7 s free=49944 largest=18432 min_ever= 9968
    Ten kilobytes left. In exactly that window the first client collapsed from
    51 chunks/s to 0 with skipped climbing to 335, while the capture loop held
    20000 us throughout -- the CPU was idle and only the radio had stopped,
    because the Wi-Fi driver allocates its TX bu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
    [snapserver.c]
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2026-09-18 diag: report per-station RSSI as the AP sees it
    With the internal-DRAM ceiling gone, four ESP32 clients plus an Android
    phone hold ~52 chunks/s and min_ever sits around 28-37 kB instead of the
    1140 B it bottomed at before. The remaining dropouts changed shape: they
    hit one client at a time, whose skipped counter climbs for a few seconds
    while every other client keeps streaming. That is the opposite of the old
    pattern, where all stations fell silent in the same second.
    So the question is now about a single link, and RSSI is what answers it. A
    client that stalls at -40 dBm is something in this code; one that stalls at
    -80 dBm is distance, an antenna or interference, and no amount of buffer
    tu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
    [snapserver.c]
2026-09-18 fix: stop a half-sent chunk from blocking a client for seconds
    One client at a time would go quiet for several seconds while every other
    client held 52 chunks/s, then recover on its own. The giveaway in the log is
    that its chunks/s went to 0 AND its time_msgs stopped at the same moment:
    both directions dead at once, which no amount of link trouble explains, and
    the user confirms it happens on clients with an external antenna and full
    signal.
    The cause is this file. Header and payload went out as two send() calls,
    and only the header was allowed to be dropped. A 26-byte header still fits
    in the socket buffer when the ~262-byte payload does not, so the send
    commits to finishing a message it c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
    [snapserver.c]
2026-09-18 fix: give the task stacks room again after snapsend3 overflowed
    A sender task crashed the server:
    W send stalled: fd=54, giving up with 171 B left
    W Wire chunk send failed (192.168.5.4); closing client
    ***ERROR*** A stack overflow in task snapsend3 has been detected.
    The stacks had been cut to just above their measured high-water marks, and
    that measurement was not what it claimed to be. A high-water mark only
    covers code that has actually run, and the reported sender=848 B free came
    entirely from the steady-state path: receive from the queue, memcpy, send.
    The failure path above runs two formatted ESP_LOGW calls, and vsnprintf
    alone wants several hundred bytes, so the first genuine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
    [snapserver.c]
2026-09-18 fix: follow the server's address on reconnect, and put RSSI in the client line
    Clients sporadically failed to come back after the server restarted -- three
    of five made it, the rest sat retrying.
    The address was captured once. snapclient_start() copied the host into
    s_host and nothing ever wrote it again, while mesh_client's GOT_IP handler
    re-resolved it on every event, logged the result and discarded it. A node
    whose first resolution was the 192.168.5.1 fallback, or whose parent changed
    so the root is reached differently, kept dialling the old address for good.
    That is the "TCP connect aborted (timeout)" loop seen earlier while the
    server was up. snapclient_set_server_host() now applies it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
    [snapserver.c]
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2026-09-18 diag: warn when the internal heap low-water mark drops
    A 12-minute run with five clients ended with
    heap: internal free=112424 B largest=31744 B min_ever=892 B
    Free was comfortable throughout and the skip counters had stopped moving, so
    by every other measure the run was clean -- but at some point the internal
    heap came within 892 bytes of empty. That is the same wall that once left
    every client at 0 chunks/s in the same second, and it went by unnoticed.
    min_ever is a low-water mark since boot: once it dips it stays put and says
    nothing about when. Warn on the drop instead, which puts it in the same
    five-second report as the client counters and the frame timing of that
    moment, so the ne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
    [snapserver.c]
2026-09-18 feat: drive the on-board WS2812 as a combined status and level indicator
    Colour says what the device is doing, brightness follows the audio level. In
    normal operation it reads as a VU meter; when something is wrong the colour
    says what, without reaching for a serial console -- red for no network,
    orange for network but no Snapserver, green for playing, cyan for the local
    input, blue for the provisioning AP.
    Both halves come from measurements that already existed. The level is the
    post-crossover output peak that audio_i2s.c has been computing for the
    diagnostic log all along, so nothing is calculated twice for the LED. It
    does get its own peak slot, because both readers clear what they read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
    [audio_i2s.c, audio_i2s.h, audio_sink.c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]
2026-09-18 fix: make the level LED actually move instead of sitting at the top
    Reported from the board: the LED is lit and the GPIO is right, but it hangs
    near full brightness continuously.
    Faster decay was the obvious knob and it is turned -- 0.12 to 0.35 per
    update, so full scale to dark now takes about 100 ms instead of 250. On its
    own that would not have fixed much: the attack is instant and a fresh peak
    arrives every 33 ms, so through anything continuous the release never gets a
    chance to run.
    The part that actually kept it pinned is the mapping. Music on this device
    measures 18000-24000 of 32767, which is 55-75 % of full scale before any
    curve is applied, so raw amplitude spent its whole life i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
    [status_led.c]
2026-09-18 feat: let the LED colour carry the level and the blink rate the state
    Colour as level, the way position works on a meter with more than one LED:
    green through yellow to red, interpolated rather than stepped, since three
    discrete colours on a single LED read as three states instead of a scale.
    Brightness still follows the level but only from 0.30 up, because hue is
    what carries the reading now and an almost-black LED has no readable hue.
    That leaves no colour free for the state, which turns out to suit the
    problem: while audio is playing there is a level to show, and when there is
    no audio path there is none. So the states without audio take the colour
    back and blink, with the rate carrying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
    [status_led.c]
2026-09-18 fix: stop the control server's snapshots stalling audio capture
    Clients joining or leaving interrupted the ones already playing, and the
    server log shows it is not the network: a join pushed frame delta from a
    steady 20000 us to avg=21089 for a full second, with every client dropping
    from 53 to 50 chunks/s at the same time. The capture loop itself slowed
    down, which is CPU or interrupt level.
    s_clients_lock is a cross-core spinlock, so holding it runs with interrupts
    off and spins the other core -- and audio_task takes it every 20 ms frame to
    collect the ready-client list. snapserver_get_clients() held it around the
    whole loop while doing a memset of 332 B plus eight strlcpy per client, so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
    [snapserver.c]
2026-09-18 fix: drop a client that has gone silent instead of feeding it forever
    A client at -43 dBm went to 0 chunks/s with time_msgs frozen at 43 and
    skipped climbing past 640, and the server kept it. Nothing was arriving from
    it and nothing could be sent to it, while the other four ran normally.
    Two things had to line up. RECV_IDLE simply loops and waits again, on
    purpose: a client that sends nothing is legal, and dropping such clients
    every ~31 s used to make them reconnect endlessly. The comment there hands
    the job of spotting a vanished peer to TCP keepalive -- but keepalive only
    probes an idle connection, and a stalled client never is idle. audio_task
    keeps queueing chunks, so TCP always has un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
    [snapserver.c]
2026-09-19 fix: let each client fall behind by up to 2.4 s instead of dropping audio
    Switching one client off cut every other client's throughput to about a
    third for ~3 s. The server could only hold ~0.4 s per client (8 queued
    chunks plus the TCP send buffer) and threw the rest away, so a stall the
    clients' 3 s buffer could have ridden out left permanent holes instead.
    Queue 120 and chunk pool 128, storage in PSRAM. A refused chunk is now
    retried rather than skipped, and chunks are dropped only once they are too
    old to play in time (bufferMs - 600 ms, capped at 2.4 s). Measured with
    four clients: skipped stays at 0 for the others and they catch up faster
    than real time once the stall clears.
    [snapserver.c]
2026-09-19 feat: voice announcements from a phone over UDP, with Opus
    A phone app arms an announcement over the existing JSON-RPC connection
    (Voice.Start/Voice.Stop on port 1705) and streams Opus packets to the server
    on UDP 1706. The server relays them to its level-1 clients only, and decodes
    them for its own speaker. Hops are left out on purpose: a relay can stall
    for seconds while it rejoins, which a buffered music stream rides out and an
    unbuffered voice channel cannot.
    Music keeps running underneath instead of stopping. Level-1 clients overlay
    the announcement on their output, level-2+ clients are muted through the
    existing ServerSettings mute. The ring buffers and the timeline stay intact,
    so mu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
    [audio_i2s.c, audio_i2s.h, audio_sink.c]
2026-09-19 feat: Android app to arm and speak voice announcements
    SnapAnnounce: a latching button arms an announcement on the server, and a
    foreground service (type microphone) captures, encodes and sends until it is
    pressed again, also with the screen locked.
    Capture is 16 kHz mono. At 48 kHz Opus chose its hybrid mode, which cost the
    server ~6 ms of CPU per 20 ms packet to decode. Wideband speech is pure SILK
    and much cheaper. Encoding uses Android's MediaCodec Opus encoder (API 29+),
    24 kbit/s VBR, one datagram per packet, sequence-numbered.
    A simple RMS AGC with a tanh limiter brings quiet phone microphones up to a
    usable level. The microphone source and the maximum gain can be set in the
    app, be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
    [OpusEncoder.kt, VoiceAnnounceService.kt]
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2026-09-20 feat: relay announcements one hop and keep their latency bounded
    Clients a few metres from the server routinely attach to each other rather
    than to it -- a neighbour two metres away is simply the stronger signal
    (seen on device: -9 dBm against -64 dBm). Those nodes were silent during an
    announcement although they stood in the same room. Server packets now carry
    a hop count, and a client forwards them to its own children, which the
    server cannot address itself because they sit behind their parent's NAPT.
    One hop, because every further one inherits the tail risk of a rearranging
    mesh.
    Who falls silent is no longer decided by the server, which cannot see past
    the first level anyway: ServerSett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
    [audio_i2s.c, audio_i2s.h, audio_sink.c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]
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2026-09-20 fix: line the server's own speaker up with its clients
    The server trailed every client audibly. Its delay line held bufferMs and
    nothing else, while three delays sat on top of it:
    - 40 ms of TX DMA queue. A frame handed to the driver is heard that much
    later, and the clients already schedule their playback that much earlier;
    the server did not.
    - 20 ms of frame length. A chunk is timestamped at the instant its frame
    starts, which is when the clients play it, but the samples only reach the
    delay line once that frame has been captured in full.
    - 20 ms more, set by ear and not derived. Candidates are the Opus encoder's
    lookahead and the client's frame assembly. Flagged in TODO.md as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
    [audio_i2s.c, audio_i2s.h, audio_sink.c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]
2026-09-20 fix: give the server's speaker the 20 ms lead its timestamps imply
    A chunk is timestamped at the instant its frame starts, which is when the
    clients play it, but those samples only reach the server's delay line once
    the frame has been captured in full. SERVER_LEAD_MS takes that frame back
    off, on top of the TX queue the previous commit accounted for.
    30, 40 and 50 ms were each tried by ear and all sounded worse, so the
    derived value stands. Tuning further that way went nowhere, and in
    hindsight it could not: the clients' own drift control moves their playback
    by more than these steps, the error swinging by tens of ms with a hard
    resync shifting it in one go. TODO.md records that the next st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
    [audio_i2s.c]
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2026-09-21 feat: volume knob on GPIO 10 for the local speaker
    A 10 kOhm potentiometer wired as a divider sets how loud this device
    plays, and nothing else: the gain is applied at the end of the output
    stage, which the Opus encoder does not pass through. Turning a server
    down therefore leaves its clients untouched, and the per-client Snapcast
    volume keeps working alongside it.
    The pin had to be on ADC1 -- ADC2 cannot be read while Wi-Fi is up, and
    here it always is -- which leaves GPIO 1 to 10. Of those, 4 to 7 are the
    I2S bus, 8 is the alternative LRCLK in audio_i2s.h and 3 is a strapping
    pin, so 10 it is. It is configurable, as is switching the whole thing
    off.
    With no potentiometer fitted the pin i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
    [audio_i2s.c, audio_i2s.h]
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2026-09-22 docs: mark GPIO 14 as possibly tied to GND
    Some boards bridge GPIO 14 to ground as an extra ground terminal next to
    the knobs. Nothing uses it today, but it must never become an output:
    driven high against that wire it would short the pin. Noted next to the
    other pin restrictions so a later change does not trip over it.
    [pots.c]
2026-09-23 Revert "docs: mark GPIO 14 as possibly tied to GND"
    GPIO 14 is not needed as an extra ground terminal after all, so the
    warning about it being hard-wired to GND no longer applies.
    This reverts commit b3e81845d25502665b4f269f1b11cce2bb5c91d5.
    [pots.c]
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
